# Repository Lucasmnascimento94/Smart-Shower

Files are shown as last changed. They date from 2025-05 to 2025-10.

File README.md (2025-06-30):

# Smart-Shower

This is an extended version of the project I made for my computer arquitecture class. 

# Goal
The Smart-Shower aims to provide a more efficient, personalized, and intelligent way to manage the shower experience. In many homes—mine included—it can take several minutes for water to reach a comfortable temperature due to the delay in hot water arriving through the pipes. Manually adjusting the valve each time is tedius and this system introduces a smart interface to control the shower valve (or other applicable valves) with a focus on user comfort, energy efficiency, and system safety.

# Features
-> Personalized Temperature Presets: Each user can save their preferred shower temperature settings for one-touch access.

-> Remote Start Functionality: Users can activate the shower remotely, allowing the water to reach the desired temperature before they step in—eliminating wait time.

-> Hot Water Monitoring: Tracks the decline of hot water temperature and alerts the user when they are about to run out—especially useful for homes that use hot water tanks.

-> Usage Tracking: Monitors water and energy usage per session. Data is logged and associated with individual users for long-term insights and potential conservation.

-> Cold Temperature Alert: Sends a warning if pipe temperatures drop too low, helping to prevent frozen or burst pipes—especially relevant for homes in colder northern climates (like mine).

# Planned Future Enhancements

-> Rich Media User Interface: Build an advanced touchscreen UI that supports media platforms such as Spotify and YouTube for a more immersive shower experience.

-> Metal Contamination Detection: Integrate a sensor to detect the presence of metals in the water—an issue that affects my home’s plumbing.

-> Smart Safety Alarms and Automation: Extend system logic to trigger alarms and automated valve actions based on detected anomalies in temperature or water quality.

The first version was made using an ATMEGA 168A, coded in assembly and all the assembled componnets were placed with loose wires in some protoboards. 

# Note
-> Because this application utilizes threads, I started to move away from the HAL functions. At first, when I started migrating from one thread to another multithreaded environment, I started adapting my working functions within certain threads. However, it was later on determined that the HAL function are not thread safe, and the programming was breaking randomly when trying to run some HAL functions. To solve this issue, I started to manipulate the register in a low level manner. Trying to avoid reinventing the wheel, I started reading the STM documentation and controlling the registers using the variable names in the RM and the macros that are provided in the STM header files. With this approach it was possible to create mutaxes and make sure that no race condition is preventing my code from running.

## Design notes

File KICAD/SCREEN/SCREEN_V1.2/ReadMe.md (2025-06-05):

## Update Overview - Power Distribution
  In this version, a critical flaw in the power distribution design has been corrected. Previously, the STM32F469IIT6 microcontroller was powered by an ASM1117-3.3 voltage regulator, stepping down from a 12V input. However, the resulting power dissipation caused the regulator to overheat, leading to unstable MCU behavior. The issue became more pronounced after introducing multi-threading in the firmware, which increased the system's current draw. At that point, the ASM1117 began to overheat severely, risking unpredictable system failures and potential board damage.

  This overheat was detected in a prior version where devices were powered by the same regulator. In an attempt to solve this issue and still use the same regulator (Because I have many in stock), I've added dedicated regulators for some devices and it worked at a certain degree. However, it was yet not possible to place the external flash memory without overheating the ASM that powers the STM32F469. Then this update aims to fix this flaw in order to be able to utilize all the intended devices and maintain the program reliability.  

## Update Overview - Touch Screen Controller
This version removes the XPT20 touchscreen controller from the design. In version 1.0 (not publicly released), issues with the touchscreen were caused by incorrect circuitry and the absence of a controller to compensate for it. The XPT20 was originally added as a workaround to assist with potential problems in reading ADC values directly—such as noise, hardware design flaws, or programming errors. However, in version 1.1, I successfully read the touchscreen using the STM32F469’s internal ADCs without needing the XPT20. As a result, this external controller has been removed in this version to simplify the design.

Version 1.1 also introduced multi-threading, with one dedicated thread continuously reading the X-axis ADC values. Based on these readings, the system calls the scan_ function, which samples multiple values to compute both X and Y coordinates. This function dynamically reconfigures the GPIOs to alternate between driving and reading different touchscreen lines. However, this dynamic GPIO switching proved problematic in a multithreaded environment. In this update, I'm testing a workaround by adding minimal extra circuitry and using an ADC multiplexer to eliminate the need for constant GPIO reconfiguration. The goal is to reduce the processing overhead and improve stability under concurrent execution.

## Update

| Removed Component |  New Component | Datasheet|
| ---:  | ---: | ---|
|AMS1117-3.3 |LM2576T-ADJ/NOPB  | https://www.ti.com/general/docs/suppproductinfo.tsp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|
| XPT20 | N/A | https://www.alldatasheet.com/html-pdf/1649104/ETC2/XPT2046/111/1/XPT2046.html |

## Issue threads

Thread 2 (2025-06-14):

Hardware | Ring Resistor

Lucasmnascimento94, 2025-06-14:
- Design a ring resistor using Nichrome wire
- Calibrate ring resistor to work as a rotation decoder

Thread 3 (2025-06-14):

Software | Valve - Position Decoder Function

Lucasmnascimento94, 2025-06-14:
- Create a function to decode ADC readings into motor's angular position
- Create a function to calibrate ring resistor in assembling process

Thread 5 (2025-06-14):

Software | Valve - Threads -> DS18B20 Function

Lucasmnascimento94, 2025-06-14:
**Create thread for Temperature Sensors**

- Read temperature from DS18B20 sensors
- Update global sensor structs

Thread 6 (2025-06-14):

Software | Valve - Threads -> UART Function

Lucasmnascimento94, 2025-06-14:
**Create a thread to handle UART**

- Configure UARTs in DMA mode to send data
- Configure UARTs in DMA mode to receive data
- Send data to memory
- Start UART transfer once data is completely transferred to memory
- Read data from memory and raise flag to indicate main thread that data is valid

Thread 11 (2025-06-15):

Create an ACK response with CRC/Checksum to check data sent

Lucasmnascimento94, 2025-06-15:
Initial results showed that the first data burst is being lost, so to avoid data loss and to make sure that commands are being received correctly, an ACK has to be implemented.

Lucasmnascimento94, 2025-07-12:
This function is now done. It reads the data received from DMA, and returns the number of bytes read, also in DMA mode.

Closed 2025-07-12.

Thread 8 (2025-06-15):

Configure UARTs in DMA mode to send data

Lucasmnascimento94, 2025-06-15:
It seems that HAL is not reliable to configure the DMA while using threads. Therefore, it is necessary to read about the DMA control register in the reference manual to control it in lower level.

###Correction###

- Writing directly in the register proved to be not efficient, and using HAL libraries is indeed a better approach.

-> DMA is now working, and mutexes were added to avoid race conditions.

Closed 2025-07-12.

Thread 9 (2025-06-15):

Configure UARTs in DMA mode to receive data

Lucasmnascimento94, 2025-06-15:

Lucasmnascimento94, 2025-07-12:
DMA_RECEIVE is now working. Mutexes are being used to avoid conflicts between DMA_RX and DMA_TX.

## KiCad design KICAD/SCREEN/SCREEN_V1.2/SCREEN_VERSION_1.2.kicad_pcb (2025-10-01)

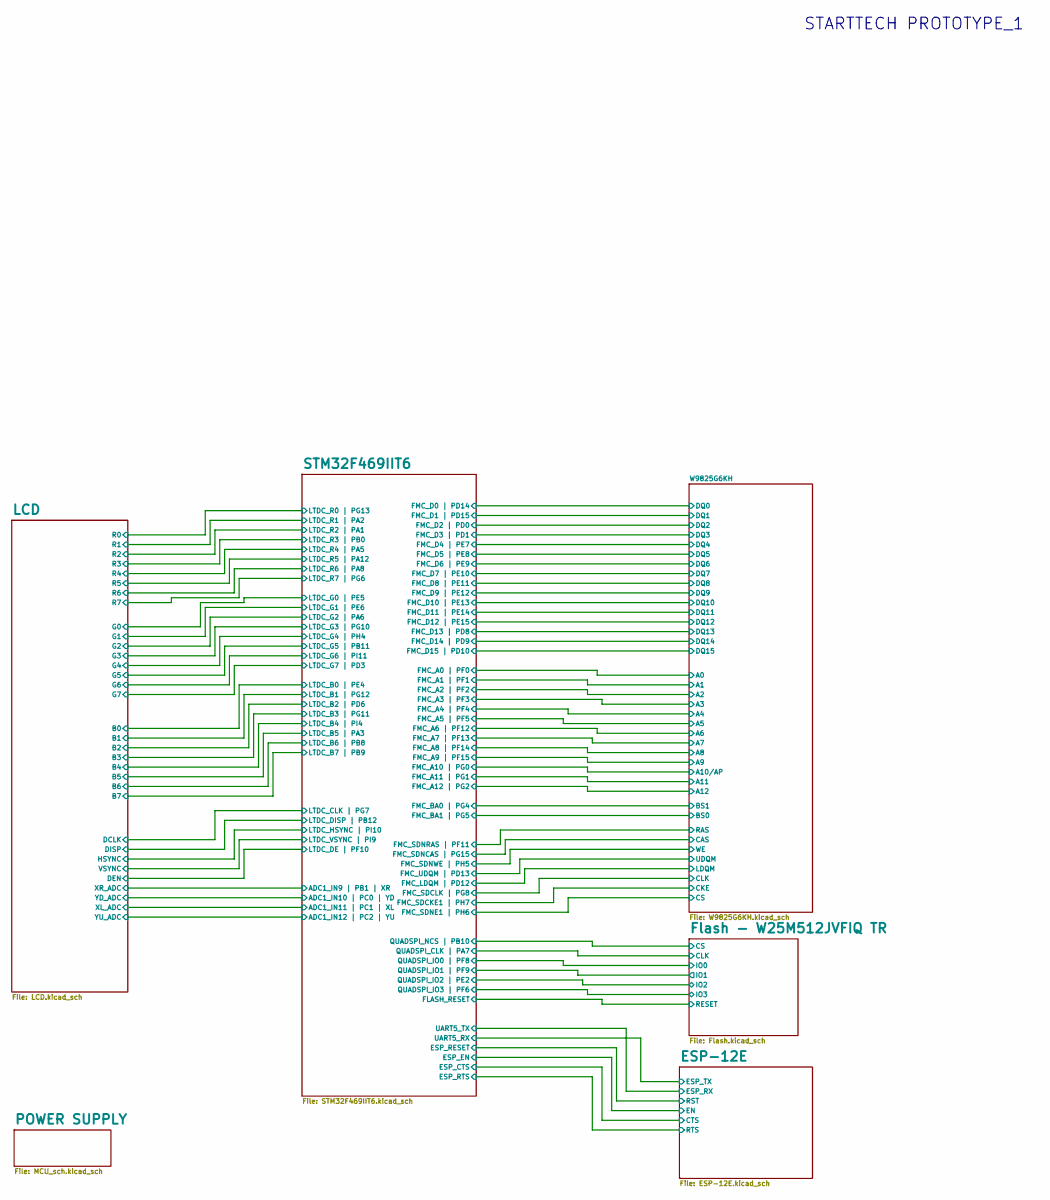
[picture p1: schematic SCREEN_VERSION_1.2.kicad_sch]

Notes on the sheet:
STARTTECH PROTOTYPE_1

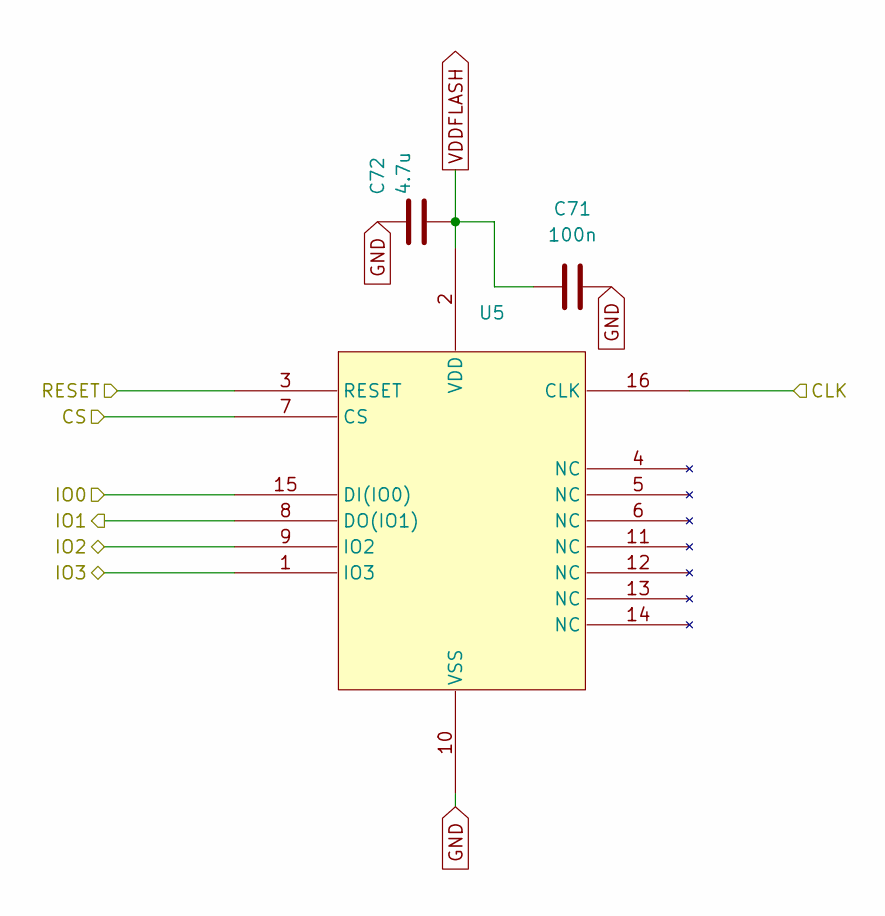
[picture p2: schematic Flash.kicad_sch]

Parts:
C71: 100n; C_0402_1005Metric
C72: 4.7u; C_0603_1608Metric
U5: W25M512JVFIQ

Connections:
/Flash - W25M512JVFIQ TR/CLK: U5.16 (CLK); also elsewhere on the board
/Flash - W25M512JVFIQ TR/CS: U5.7 (CS); also elsewhere on the board
/Flash - W25M512JVFIQ TR/IO0: U5.15 (DI(IO0)); also elsewhere on the board
/Flash - W25M512JVFIQ TR/IO1: U5.8 (DO(IO1)); also elsewhere on the board
/Flash - W25M512JVFIQ TR/IO2: U5.9 (IO2); also elsewhere on the board
/Flash - W25M512JVFIQ TR/IO3: U5.1 (IO3); also elsewhere on the board
/Flash - W25M512JVFIQ TR/RESET: U5.3 (RESET); also elsewhere on the board
GND: C71.2, C72.1, U5.10 (VSS); also elsewhere on the board
VDDFLASH: C71.1, C72.2, U5.2 (VDD); also elsewhere on the board

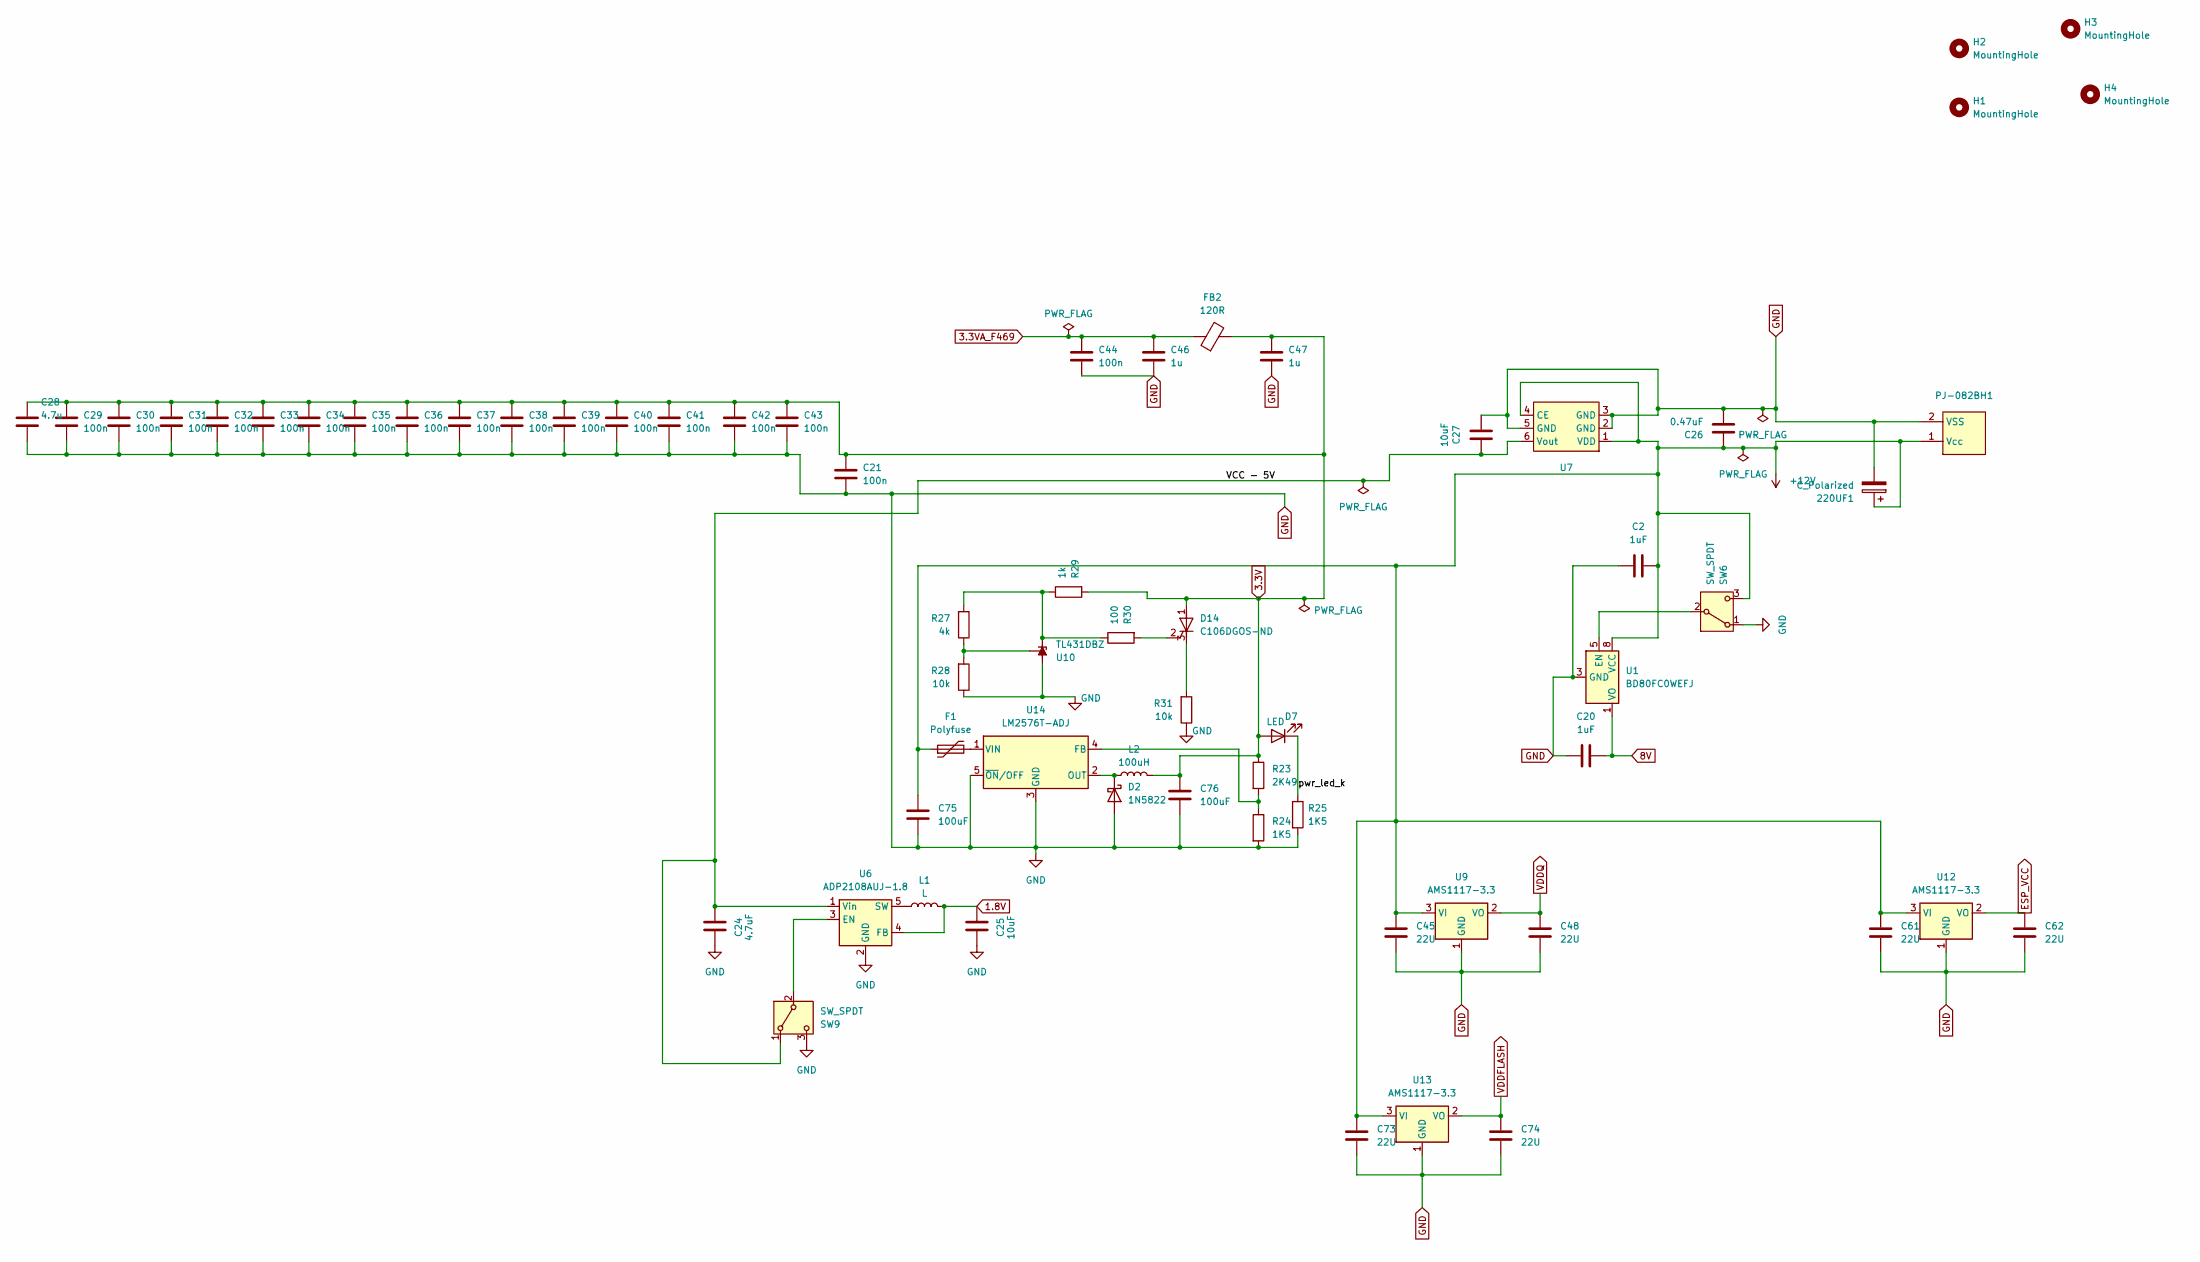
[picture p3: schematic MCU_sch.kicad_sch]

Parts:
220UF1: C_Polarized; C_Disc_D3.0mm_W1.6mm_P2.50mm
C2, C20: 1uF; C_0603_1608Metric
C21, C29, C30, C31, C32, C33, C34, C35, C36, C37, C38, C39, C40, C41, C42, C43, C44: 100n; C_0402_1005Metric
C24: 4.7uF; C_0603_1608Metric
C25, C27: 10uF; C_0805_2012Metric
C26: 0.47uF; C_0603_1608Metric
C28: 4.7u; C_0603_1608Metric
C45, C48, C61, C62, C73, C74: 22U; C_0805_2012Metric
C46, C47: 1u; C_0603_1608Metric
C75, C76: 100uF; C_1210_3225Metric_Pad1.33x2.70mm_HandSolder
D2: 1N5822; D_DO-201AD_P15.24mm_Horizontal
D7: LED; LED_0603_1608Metric
D14: C106DGOS-ND; SIP3_11.6x8.5mm
F1: Polyfuse; Fuse_1206_3216Metric
FB2: 120R; L_0603_1608Metric
H1, H2, H3, H4: MountingHole; MountingHole_3.2mm_M3
L1: L; L_0603_1608Metric_Pad1.05x0.95mm_HandSolder
L2: 100uH; SRN8040-101M
PJ-082BH1: BarrelJack_CUI_PJ-063AH_Horizontal
R23: 2K49; R_0402_1005Metric
R24, R25: 1K5; R_0402_1005Metric
R27: 4k; R_0402_1005Metric
R28, R31: 10k; R_0402_1005Metric
R29: 1k; R_0402_1005Metric
R30: 100; R_0402_1005Metric
SW6, SW9: SW_SPDT; SW_Slide_SPDT_Straight_CK_OS102011MS2Q
U1: BD80FC0WEFJ; HTSOP-8-1EP_3.9x4.9mm_P1.27mm_EP2.4x3.2mm
U6: ADP2108AUJ-1.8; TSOT-23-5
U7: R1501S050B-E2-FE
U9, U12, U13: AMS1117-3.3; SOT-223-3_TabPin2
U10: TL431DBZ; SOT-23
U14: LM2576T-ADJ; TO-220-5_Vertical

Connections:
1.8V: C25.1, L1.2, U6.4 (FB); also elsewhere on the board
3.3V: C21.1, C28.1, C29.1, C30.1, C31.1, C32.1, C33.1, C34.1, C35.1, C36.1, C37.1, C38.1, C39.1, C40.1, C41.1, C42.1, C43.1, C47.1, C76.1, D7.2 (A), D14.1 (A), FB2.2, L2.2, R23.1, R29.2; also elsewhere on the board
3.3VA_F469: C44.1, C46.1, FB2.1; also elsewhere on the board
8V: C20.1, U1.1 (VO); also elsewhere on the board
+12V: 220UF1.1, C2.1, C26.1, C45.1, C61.1, C73.1, C75.1, F1.1, PJ-082BH1.1 (Vcc), SW6.3 (C), U1.8 (VCC), U7.1 (VDD), U7.4 (CE), U9.3 (VI), U12.3 (VI), U13.3 (VI)
/POWER SUPPLY/VCC - 5V: C24.1, C27.2, SW9.1 (A), U6.1 (Vin), U7.6 (Vout)
/POWER SUPPLY/pwr_led_k: D7.1 (K), R25.1
ESP_VCC: C62.1, U12.2 (VO); also elsewhere on the board
GND: 220UF1.2, C2.2, C20.2, C21.2, C24.2, C25.2, C26.2, C27.1, C28.2, C29.2, C30.2, C31.2, C32.2, C33.2, C34.2, C35.2, C36.2, C37.2, C38.2, C39.2, C40.2, C41.2, C42.2, C43.2, C44.2, C45.2, C46.2, C47.2, C48.2, C61.2, C62.2, C73.2, C74.2, C75.2, C76.2, D2.2 (A), PJ-082BH1.2 (VSS), R24.2, R25.2, R28.1, R31.1, SW6.1 (A), SW9.3 (C), U1.3 (GND), U1.9 (GND), U6.2 (GND), U7.2 (GND), U7.3 (GND), U7.5 (GND), U9.1 (GND), U10.3 (A), U12.1 (GND), U13.1 (GND), U14.3 (GND), U14.5 (~ON/OFF); also elsewhere on the board
unnamed: D2.1 (K), L2.1, U14.2 (OUT)
unnamed: D14.2 (G), R30.2
unnamed: D14.3 (K), R31.2
unnamed: SW6.2 (B), U1.5 (EN)
unnamed: SW9.2 (B), U6.3 (EN)
unnamed: L1.1, U6.5 (SW)
unnamed: R27.2, R29.1, R30.1, U10.1 (K)
unnamed: R27.1, R28.2, U10.2 (REF)
unnamed: R23.2, R24.1, U14.4 (FB)
unnamed: F1.2, U14.1 (VIN)
VDDFLASH: C74.1, U13.2 (VO); also elsewhere on the board
VDDQ: C48.1, U9.2 (VO); also elsewhere on the board

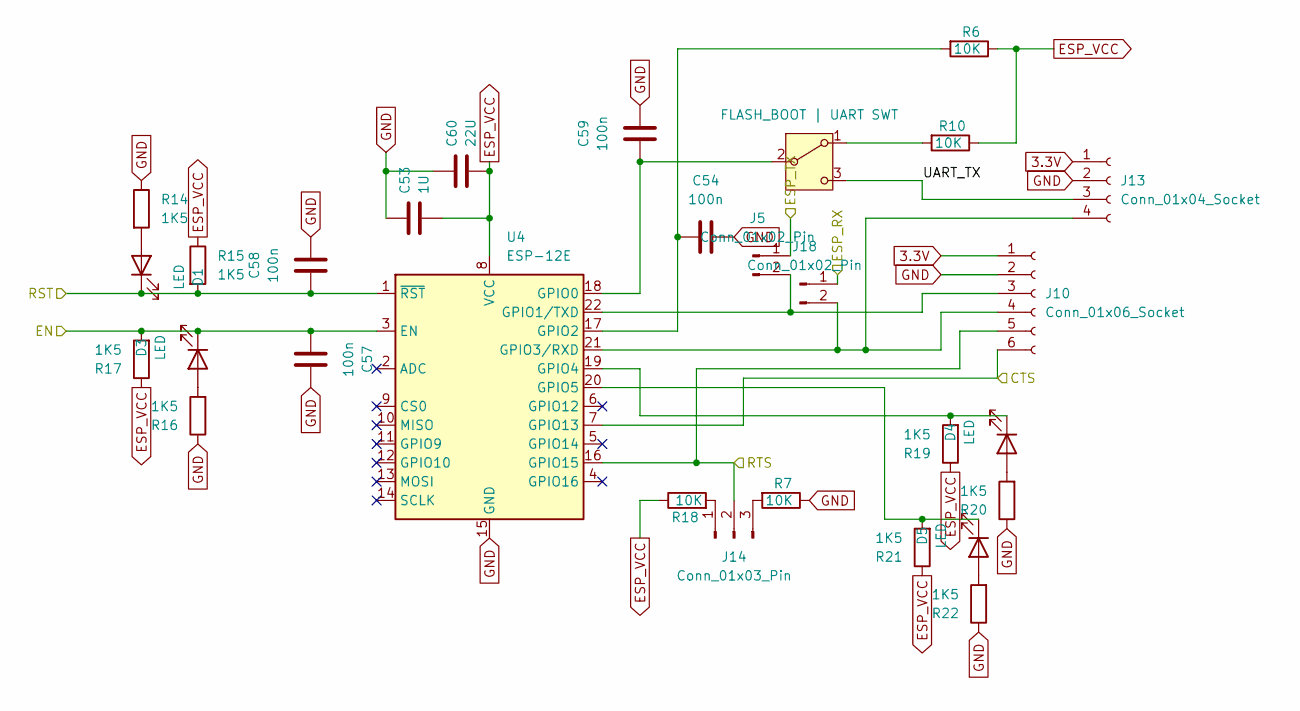
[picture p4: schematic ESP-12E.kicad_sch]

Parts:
C53: 1U; C_0805_2012Metric
C54, C57, C58, C59: 100n; C_0402_1005Metric
C60: 22U; C_0805_2012Metric
D1, D3, D4, D5: LED; LED_0603_1608Metric
J5, J18: Conn_01x02_Pin; PinSocket_1x02_P2.54mm_Vertical
J10: Conn_01x06_Socket; PinSocket_1x06_P2.54mm_Vertical
J13: Conn_01x04_Socket; PinSocket_1x04_P2.54mm_Vertical
J14: Conn_01x03_Pin; PinSocket_1x03_P2.54mm_Vertical
R6, R7, R10, R18: 10K; R_0402_1005Metric
R14, R15, R16, R17, R19, R20, R21, R22: 1K5; R_0402_1005Metric
SW5: FLASH_BOOT | UART SWT; SW_Slide_SPDT_Straight_CK_OS102011MS2Q
U4: ESP-12E

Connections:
3.3V: J10.1, J13.1; also elsewhere on the board
/ESP-12E/CTS: J10.6, U4.7 (GPIO13); also elsewhere on the board
/ESP-12E/EN: C57.1, D3.1 (K), R17.2, U4.3 (EN); also elsewhere on the board
/ESP-12E/ESP_RX: J18.1; also elsewhere on the board
/ESP-12E/ESP_TX: J5.1; also elsewhere on the board
/ESP-12E/RST: C58.1, D1.1 (K), R15.2, U4.1 (~RST); also elsewhere on the board
/ESP-12E/RTS: J10.5, J14.2, U4.16 (GPIO15); also elsewhere on the board
/ESP-12E/UART_TX: J13.3, SW5.3 (C)
ESP_VCC: C53.2, C60.2, R6.1, R10.1, R15.1, R17.1, R18.1, R19.1, R21.1, U4.8 (VCC); also elsewhere on the board
GND: C53.1, C54.2, C57.2, C58.2, C59.2, C60.1, J10.2, J13.2, R7.1, R14.1, R16.1, R20.1, R22.1, U4.15 (GND); also elsewhere on the board
unnamed: D1.2 (A), R14.2
unnamed: D3.2 (A), R16.2
unnamed: D4.2 (A), R20.2
unnamed: D4.1 (K), R19.2, U4.19 (GPIO4)
unnamed: D5.2 (A), R22.2
unnamed: D5.1 (K), R21.2, U4.20 (GPIO5)
unnamed: J5.2, J10.3, U4.22 (GPIO1/TXD)
unnamed: J10.4, J13.4, J18.2, U4.21 (GPIO3/RXD)
unnamed: J14.1, R18.2
unnamed: J14.3, R7.2
unnamed: R10.2, SW5.1 (A)
unnamed: C59.1, SW5.2 (B), U4.18 (GPIO0)
unnamed: C54.1, R6.2, U4.17 (GPIO2)

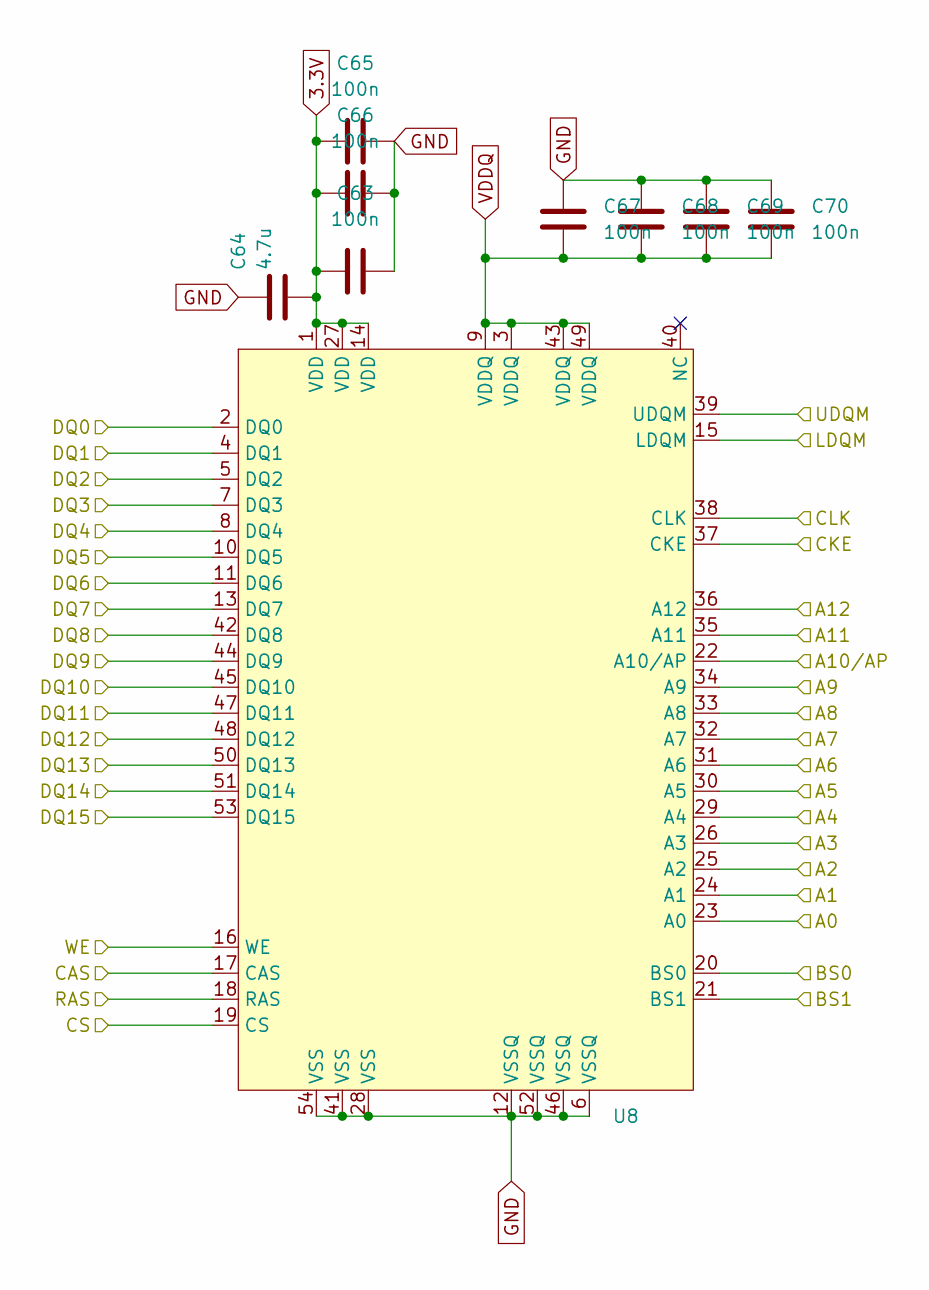
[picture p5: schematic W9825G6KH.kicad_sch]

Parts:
C63, C65, C66, C67, C68, C69, C70: 100n; C_0402_1005Metric
C64: 4.7u; C_0603_1608Metric
U8: W9825G6KH

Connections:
3.3V: C63.1, C64.2, C65.1, C66.1, U8.1 (VDD), U8.14 (VDD), U8.27 (VDD); also elsewhere on the board
/STM32F469IIT6/FMC_A0 | PF0: U8.23 (A0); also elsewhere on the board
/STM32F469IIT6/FMC_A1 | PF1: U8.24 (A1); also elsewhere on the board
/STM32F469IIT6/FMC_A2 | PF2: U8.25 (A2); also elsewhere on the board
/STM32F469IIT6/FMC_A3 | PF3: U8.26 (A3); also elsewhere on the board
/STM32F469IIT6/FMC_A4 | PF4: U8.29 (A4); also elsewhere on the board
/STM32F469IIT6/FMC_A5 | PF5: U8.30 (A5); also elsewhere on the board
/STM32F469IIT6/FMC_A6 | PF12: U8.31 (A6); also elsewhere on the board
/STM32F469IIT6/FMC_A7 | PF13: U8.32 (A7); also elsewhere on the board
/STM32F469IIT6/FMC_A8 | PF14: U8.33 (A8); also elsewhere on the board
/STM32F469IIT6/FMC_A9 | PF15: U8.34 (A9); also elsewhere on the board
/STM32F469IIT6/FMC_A10 | PG0: U8.22 (A10/AP); also elsewhere on the board
/STM32F469IIT6/FMC_A11 | PG1: U8.35 (A11); also elsewhere on the board
/STM32F469IIT6/FMC_A12 | PG2: U8.36 (A12); also elsewhere on the board
/STM32F469IIT6/FMC_BA0 | PG4: U8.21 (BS1); also elsewhere on the board
/STM32F469IIT6/FMC_BA1 | PG5: U8.20 (BS0); also elsewhere on the board
/STM32F469IIT6/FMC_D0 | PD14: U8.2 (DQ0); also elsewhere on the board
/STM32F469IIT6/FMC_D1 | PD15: U8.4 (DQ1); also elsewhere on the board
/STM32F469IIT6/FMC_D2 | PD0: U8.5 (DQ2); also elsewhere on the board
/STM32F469IIT6/FMC_D3 | PD1: U8.7 (DQ3); also elsewhere on the board
/STM32F469IIT6/FMC_D4 | PE7: U8.8 (DQ4); also elsewhere on the board
/STM32F469IIT6/FMC_D5 | PE8: U8.10 (DQ5); also elsewhere on the board
/STM32F469IIT6/FMC_D6 | PE9: U8.11 (DQ6); also elsewhere on the board
/STM32F469IIT6/FMC_D7 | PE10: U8.13 (DQ7); also elsewhere on the board
/STM32F469IIT6/FMC_D8 | PE11: U8.42 (DQ8); also elsewhere on the board
/STM32F469IIT6/FMC_D9 | PE12: U8.44 (DQ9); also elsewhere on the board
/STM32F469IIT6/FMC_D10 | PE13: U8.45 (DQ10); also elsewhere on the board
/STM32F469IIT6/FMC_D11 | PE14: U8.47 (DQ11); also elsewhere on the board
/STM32F469IIT6/FMC_D12 | PE15: U8.48 (DQ12); also elsewhere on the board
/STM32F469IIT6/FMC_D13 | PD8: U8.50 (DQ13); also elsewhere on the board
/STM32F469IIT6/FMC_D14 | PD9: U8.51 (DQ14); also elsewhere on the board
/STM32F469IIT6/FMC_D15 | PD10: U8.53 (DQ15); also elsewhere on the board
/STM32F469IIT6/FMC_LDQM | PD12: U8.15 (LDQM); also elsewhere on the board
/STM32F469IIT6/FMC_SDCKE1 | PH7: U8.37 (CKE); also elsewhere on the board
/STM32F469IIT6/FMC_SDCLK | PG8: U8.38 (CLK); also elsewhere on the board
/STM32F469IIT6/FMC_SDNCAS | PG15: U8.17 (CAS); also elsewhere on the board
/STM32F469IIT6/FMC_SDNE1 | PH6: U8.19 (CS); also elsewhere on the board
/STM32F469IIT6/FMC_SDNRAS | PF11: U8.18 (RAS); also elsewhere on the board
/STM32F469IIT6/FMC_SDNWE | PH5: U8.16 (WE); also elsewhere on the board
/STM32F469IIT6/FMC_UDQM | PD13: U8.39 (UDQM); also elsewhere on the board
GND: C63.2, C64.1, C65.2, C66.2, C67.2, C68.2, C69.2, C70.2, U8.6 (VSSQ), U8.12 (VSSQ), U8.28 (VSS), U8.41 (VSS), U8.46 (VSSQ), U8.52 (VSSQ), U8.54 (VSS); also elsewhere on the board
VDDQ: C67.1, C68.1, C69.1, C70.1, U8.3 (VDDQ), U8.9 (VDDQ), U8.43 (VDDQ), U8.49 (VDDQ); also elsewhere on the board

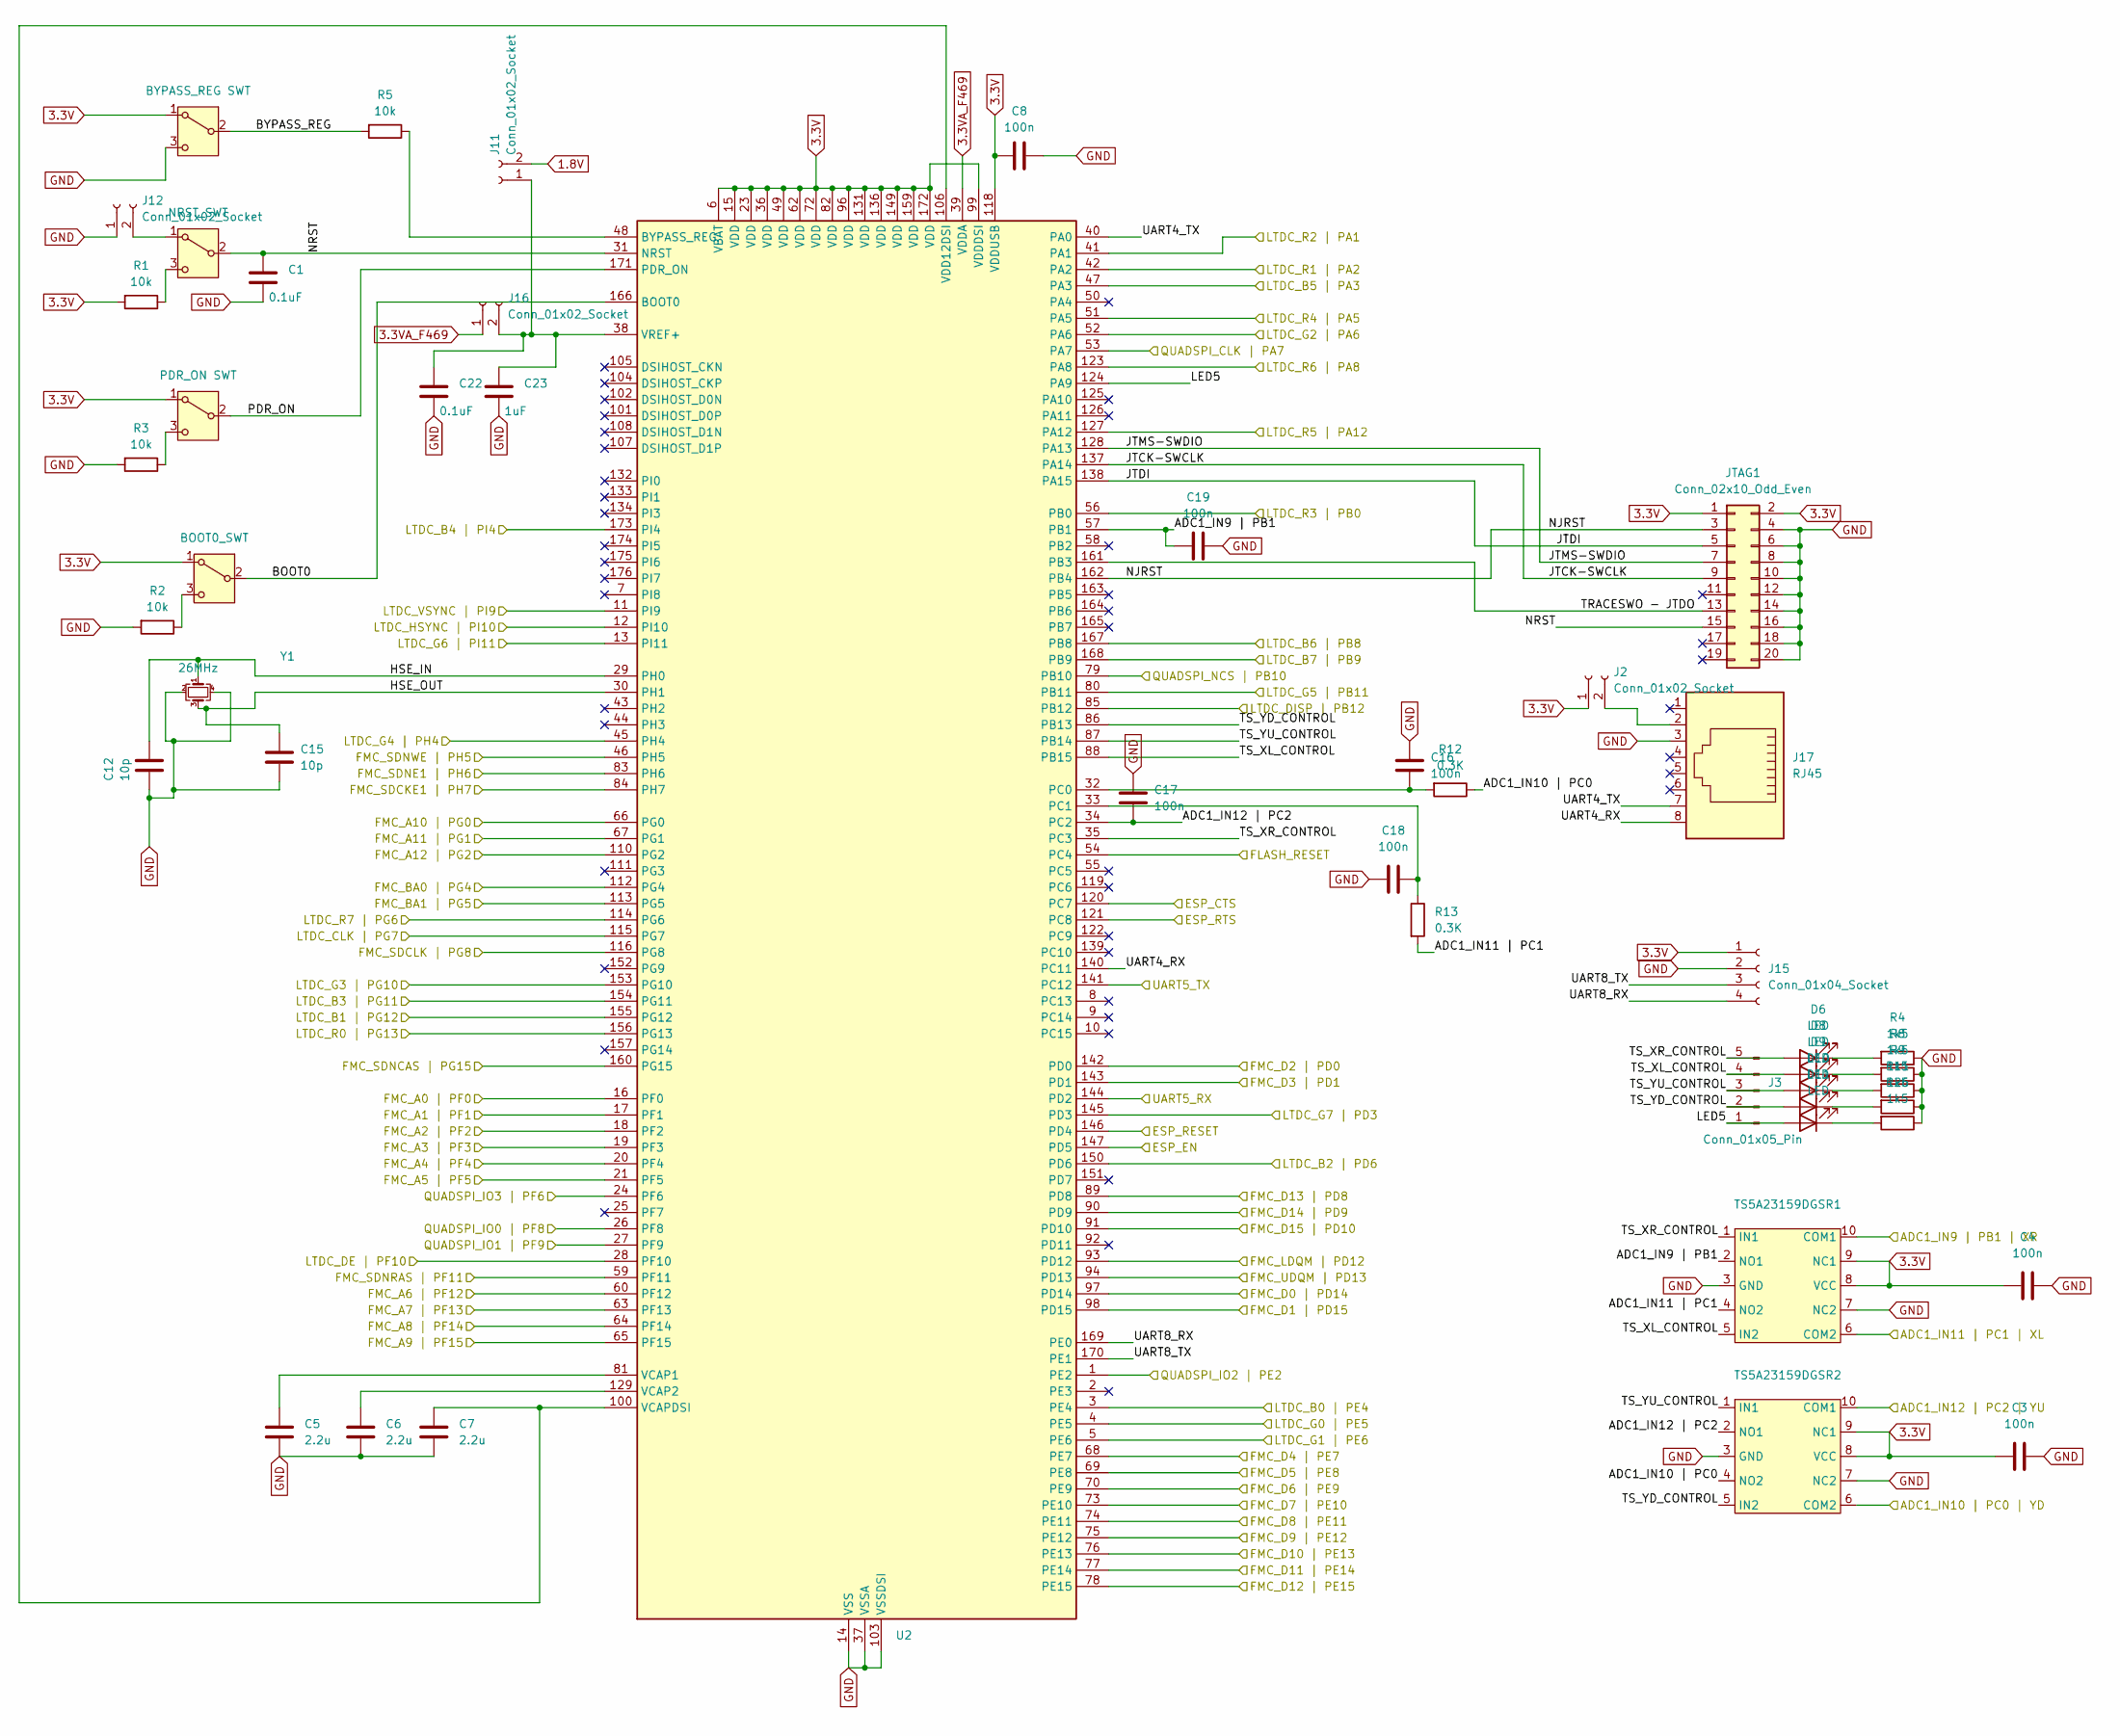
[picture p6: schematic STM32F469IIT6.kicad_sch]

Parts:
C1, C22: 0.1uF; C_0402_1005Metric
C3, C4, C8, C16, C17, C18, C19: 100n; C_0402_1005Metric
C5, C6, C7: 2.2u; C_0402_1005Metric
C12, C15: 10p; C_0402_1005Metric
C23: 1uF; C_0402_1005Metric
D6, D8, D9, D10, D11: LED; LED_0603_1608Metric
J2, J11, J12, J16: Conn_01x02_Socket; PinSocket_1x02_P2.54mm_Vertical
J3: Conn_01x05_Pin; PinSocket_1x05_P2.54mm_Vertical
J15: Conn_01x04_Socket; PinSocket_1x04_P2.54mm_Vertical
J17: RJ45; RJ45_Pulse_JXD6-0001NL_Horizontal
JTAG1: Conn_02x10_Odd_Even; IDC-Header_2x10_P2.54mm_Vertical
R1, R2, R3, R5: 10k; R_0402_1005Metric
R4, R8, R9, R11, R26: 1k5; R_0402_1005Metric
R12, R13: 0.3K; R_0402_1005Metric
SW1: BOOT0_SWT; SW_Slide_SPDT_Straight_CK_OS102011MS2Q
SW2: NRST_SWT; SW_Slide_SPDT_Straight_CK_OS102011MS2Q
SW3: PDR_ON SWT; SW_Slide_SPDT_Straight_CK_OS102011MS2Q
SW4: BYPASS_REG SWT; SW_Slide_SPDT_Straight_CK_OS102011MS2Q
TS5A23159DGSR1, TS5A23159DGSR2: TS5A23159DGSR
U2: STM32F469IITx; LQFP-176_24x24mm_P0.5mm
Y1: 26MHz; Crystal_SMD_3225-4Pin_3.2x2.5mm_HandSoldering

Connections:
1.8V: J11.2; also elsewhere on the board
3.3V: C3.1, C4.1, C8.1, J2.1, J15.1, JTAG1.1, JTAG1.2, R1.2, SW1.1 (A), SW3.1 (A), SW4.1 (A), TS5A23159DGSR1.8 (VCC), TS5A23159DGSR1.9 (NC1), TS5A23159DGSR2.8 (VCC), TS5A23159DGSR2.9 (NC1), U2.6 (VBAT), U2.15 (VDD), U2.23 (VDD), U2.36 (VDD), U2.49 (VDD), U2.62 (VDD), U2.72 (VDD), U2.82 (VDD), U2.96 (VDD), U2.99 (VDDDSI), U2.118 (VDDUSB), U2.131 (VDD), U2.136 (VDD), U2.149 (VDD), U2.159 (VDD), U2.172 (VDD); also elsewhere on the board
3.3VA_F469: J16.1, U2.39 (VDDA); also elsewhere on the board
/ESP-12E/CTS: U2.120 (PC7); also elsewhere on the board
/ESP-12E/EN: U2.147 (PD5); also elsewhere on the board
/ESP-12E/ESP_RX: U2.141 (PC12); also elsewhere on the board
/ESP-12E/ESP_TX: U2.144 (PD2); also elsewhere on the board
/ESP-12E/RST: U2.146 (PD4); also elsewhere on the board
/ESP-12E/RTS: U2.121 (PC8); also elsewhere on the board
/Flash - W25M512JVFIQ TR/CLK: U2.53 (PA7); also elsewhere on the board
/Flash - W25M512JVFIQ TR/CS: U2.79 (PB10); also elsewhere on the board
/Flash - W25M512JVFIQ TR/IO0: U2.26 (PF8); also elsewhere on the board
/Flash - W25M512JVFIQ TR/IO1: U2.27 (PF9); also elsewhere on the board
/Flash - W25M512JVFIQ TR/IO2: U2.1 (PE2); also elsewhere on the board
/Flash - W25M512JVFIQ TR/IO3: U2.24 (PF6); also elsewhere on the board
/Flash - W25M512JVFIQ TR/RESET: U2.54 (PC4); also elsewhere on the board
/LCD/B0: U2.3 (PE4); also elsewhere on the board
/LCD/B1: U2.155 (PG12); also elsewhere on the board
/LCD/B2: U2.150 (PD6); also elsewhere on the board
/LCD/B3: U2.154 (PG11); also elsewhere on the board
/LCD/B4: U2.173 (PI4); also elsewhere on the board
/LCD/B5: U2.47 (PA3); also elsewhere on the board
/LCD/B6: U2.167 (PB8); also elsewhere on the board
/LCD/B7: U2.168 (PB9); also elsewhere on the board
/LCD/DCLK: U2.115 (PG7); also elsewhere on the board
/LCD/DEN: U2.28 (PF10); also elsewhere on the board
/LCD/DISP: U2.85 (PB12); also elsewhere on the board
/LCD/G0: U2.4 (PE5); also elsewhere on the board
/LCD/G1: U2.5 (PE6); also elsewhere on the board
/LCD/G2: U2.52 (PA6); also elsewhere on the board
/LCD/G3: U2.153 (PG10); also elsewhere on the board
/LCD/G4: U2.45 (PH4); also elsewhere on the board
/LCD/G5: U2.80 (PB11); also elsewhere on the board
/LCD/G6: U2.13 (PI11); also elsewhere on the board
/LCD/G7: U2.145 (PD3); also elsewhere on the board
/LCD/HSYNC: U2.12 (PI10); also elsewhere on the board
/LCD/R0: U2.156 (PG13); also elsewhere on the board
/LCD/R1: U2.42 (PA2); also elsewhere on the board
/LCD/R2: U2.41 (PA1); also elsewhere on the board
/LCD/R3: U2.56 (PB0); also elsewhere on the board
/LCD/R4: U2.51 (PA5); also elsewhere on the board
/LCD/R5: U2.127 (PA12); also elsewhere on the board
/LCD/R6: U2.123 (PA8); also elsewhere on the board
/LCD/R7: U2.114 (PG6); also elsewhere on the board
/LCD/VSYNC: U2.11 (PI9); also elsewhere on the board
/LCD/XL_ADC: TS5A23159DGSR1.6 (COM2); also elsewhere on the board
/LCD/XR_ADC: TS5A23159DGSR1.10 (COM1); also elsewhere on the board
/LCD/YD_ADC: TS5A23159DGSR2.6 (COM2); also elsewhere on the board
/LCD/YU_ADC: TS5A23159DGSR2.10 (COM1); also elsewhere on the board
/STM32F469IIT6/ADC1_IN9 | PB1: C19.1, TS5A23159DGSR1.2 (NO1), U2.57 (PB1)
/STM32F469IIT6/ADC1_IN10 | PC0: R12.1, TS5A23159DGSR2.4 (NO2)
/STM32F469IIT6/ADC1_IN11 | PC1: R13.2, TS5A23159DGSR1.4 (NO2)
/STM32F469IIT6/ADC1_IN12 | PC2: C17.2, TS5A23159DGSR2.2 (NO1), U2.34 (PC2)
/STM32F469IIT6/BOOT0: SW1.2 (B), U2.166 (BOOT0); also elsewhere on the board
/STM32F469IIT6/BYPASS_REG: R5.2, SW4.2 (B); also elsewhere on the board
/STM32F469IIT6/FMC_A0 | PF0: U2.16 (PF0); also elsewhere on the board
/STM32F469IIT6/FMC_A1 | PF1: U2.17 (PF1); also elsewhere on the board
/STM32F469IIT6/FMC_A2 | PF2: U2.18 (PF2); also elsewhere on the board
/STM32F469IIT6/FMC_A3 | PF3: U2.19 (PF3); also elsewhere on the board
/STM32F469IIT6/FMC_A4 | PF4: U2.20 (PF4); also elsewhere on the board
/STM32F469IIT6/FMC_A5 | PF5: U2.21 (PF5); also elsewhere on the board
/STM32F469IIT6/FMC_A6 | PF12: U2.60 (PF12); also elsewhere on the board
/STM32F469IIT6/FMC_A7 | PF13: U2.63 (PF13); also elsewhere on the board
/STM32F469IIT6/FMC_A8 | PF14: U2.64 (PF14); also elsewhere on the board
/STM32F469IIT6/FMC_A9 | PF15: U2.65 (PF15); also elsewhere on the board
/STM32F469IIT6/FMC_A10 | PG0: U2.66 (PG0); also elsewhere on the board
/STM32F469IIT6/FMC_A11 | PG1: U2.67 (PG1); also elsewhere on the board
/STM32F469IIT6/FMC_A12 | PG2: U2.110 (PG2); also elsewhere on the board
/STM32F469IIT6/FMC_BA0 | PG4: U2.112 (PG4); also elsewhere on the board
/STM32F469IIT6/FMC_BA1 | PG5: U2.113 (PG5); also elsewhere on the board
/STM32F469IIT6/FMC_D0 | PD14: U2.97 (PD14); also elsewhere on the board
/STM32F469IIT6/FMC_D1 | PD15: U2.98 (PD15); also elsewhere on the board
/STM32F469IIT6/FMC_D2 | PD0: U2.142 (PD0); also elsewhere on the board
/STM32F469IIT6/FMC_D3 | PD1: U2.143 (PD1); also elsewhere on the board
/STM32F469IIT6/FMC_D4 | PE7: U2.68 (PE7); also elsewhere on the board
/STM32F469IIT6/FMC_D5 | PE8: U2.69 (PE8); also elsewhere on the board
/STM32F469IIT6/FMC_D6 | PE9: U2.70 (PE9); also elsewhere on the board
/STM32F469IIT6/FMC_D7 | PE10: U2.73 (PE10); also elsewhere on the board
/STM32F469IIT6/FMC_D8 | PE11: U2.74 (PE11); also elsewhere on the board
/STM32F469IIT6/FMC_D9 | PE12: U2.75 (PE12); also elsewhere on the board
/STM32F469IIT6/FMC_D10 | PE13: U2.76 (PE13); also elsewhere on the board
/STM32F469IIT6/FMC_D11 | PE14: U2.77 (PE14); also elsewhere on the board
/STM32F469IIT6/FMC_D12 | PE15: U2.78 (PE15); also elsewhere on the board
/STM32F469IIT6/FMC_D13 | PD8: U2.89 (PD8); also elsewhere on the board
/STM32F469IIT6/FMC_D14 | PD9: U2.90 (PD9); also elsewhere on the board
/STM32F469IIT6/FMC_D15 | PD10: U2.91 (PD10); also elsewhere on the board
/STM32F469IIT6/FMC_LDQM | PD12: U2.93 (PD12); also elsewhere on the board
/STM32F469IIT6/FMC_SDCKE1 | PH7: U2.84 (PH7); also elsewhere on the board
/STM32F469IIT6/FMC_SDCLK | PG8: U2.116 (PG8); also elsewhere on the board
/STM32F469IIT6/FMC_SDNCAS | PG15: U2.160 (PG15); also elsewhere on the board
/STM32F469IIT6/FMC_SDNE1 | PH6: U2.83 (PH6); also elsewhere on the board
/STM32F469IIT6/FMC_SDNRAS | PF11: U2.59 (PF11); also elsewhere on the board
/STM32F469IIT6/FMC_SDNWE | PH5: U2.46 (PH5); also elsewhere on the board
/STM32F469IIT6/FMC_UDQM | PD13: U2.94 (PD13); also elsewhere on the board
/STM32F469IIT6/HSE_IN: C12.1, U2.29 (PH0), Y1.1
/STM32F469IIT6/HSE_OUT: C15.1, U2.30 (PH1), Y1.3
/STM32F469IIT6/JTCK-SWCLK: JTAG1.9, U2.137 (PA14)
/STM32F469IIT6/JTDI: JTAG1.5, U2.138 (PA15)
/STM32F469IIT6/JTMS-SWDIO: JTAG1.7, U2.128 (PA13)
/STM32F469IIT6/LED5: D11.2 (A), J3.1, U2.124 (PA9)
/STM32F469IIT6/NJRST: JTAG1.3, U2.162 (PB4)
/STM32F469IIT6/NRST: C1.2, JTAG1.15, SW2.2 (B), U2.31 (NRST); also elsewhere on the board
/STM32F469IIT6/PDR_ON: SW3.2 (B), U2.171 (PDR_ON); also elsewhere on the board
/STM32F469IIT6/TRACESWO - JTDO: JTAG1.13, U2.161 (PB3)
/STM32F469IIT6/TS_XL_CONTROL: D8.2 (A), J3.4, TS5A23159DGSR1.5 (IN2), U2.88 (PB15)
/STM32F469IIT6/TS_XR_CONTROL: D6.2 (A), J3.5, TS5A23159DGSR1.1 (IN1), U2.35 (PC3)
/STM32F469IIT6/TS_YD_CONTROL: D10.2 (A), J3.2, TS5A23159DGSR2.5 (IN2), U2.86 (PB13)
/STM32F469IIT6/TS_YU_CONTROL: D9.2 (A), J3.3, TS5A23159DGSR2.1 (IN1), U2.87 (PB14)
/STM32F469IIT6/UART4_RX: J17.8, U2.140 (PC11)
/STM32F469IIT6/UART4_TX: J17.7, U2.40 (PA0)
/STM32F469IIT6/UART8_RX: J15.4, U2.169 (PE0)
/STM32F469IIT6/UART8_TX: J15.3, U2.170 (PE1)
GND: C1.1, C3.2, C4.2, C5.2, C6.2, C7.2, C8.2, C12.2, C15.2, C16.1, C17.1, C18.1, C19.2, C22.1, C23.1, J12.1, J15.2, J17.3, JTAG1.4, JTAG1.6, JTAG1.8, JTAG1.10, JTAG1.12, JTAG1.14, JTAG1.16, JTAG1.18, JTAG1.20, R2.2, R3.2, R4.1, R8.1, R9.1, R11.1, R26.1, SW4.3 (C), TS5A23159DGSR1.3 (GND), TS5A23159DGSR1.7 (NC2), TS5A23159DGSR2.3 (GND), TS5A23159DGSR2.7 (NC2), U2.14 (VSS), U2.22 (VSS), U2.37 (VSSA), U2.61 (VSS), U2.71 (VSS), U2.95 (VSS), U2.103 (VSSDSI), U2.109 (VSSDSI), U2.117 (VSS), U2.130 (VSS), U2.135 (VSS), U2.148 (VSS), U2.158 (VSS), Y1.2, Y1.4; also elsewhere on the board
unnamed: D6.1 (K), R4.2
unnamed: D8.1 (K), R8.2
unnamed: D9.1 (K), R9.2
unnamed: D10.1 (K), R11.2
unnamed: D11.1 (K), R26.2
unnamed: J2.2, J17.2
unnamed: C22.2, C23.2, J11.1, J16.2, U2.38 (VREF+)
unnamed 137: J12.2, SW2.1 (A); also elsewhere on the board
unnamed 140: R2.1, SW1.3 (C); also elsewhere on the board
unnamed 141: R1.1, SW2.3 (C); also elsewhere on the board
unnamed 142: R3.1, SW3.3 (C); also elsewhere on the board
unnamed: R5.1, U2.48 (BYPASS_REG)
unnamed: C16.2, R12.2, U2.32 (PC0)
unnamed: C18.2, R13.1, U2.33 (PC1)
unnamed: C5.1, U2.81 (VCAP1)
unnamed: C6.1, U2.129 (VCAP2)
unnamed: C7.1, U2.100 (VCAPDSI), U2.106 (VDD12DSI)

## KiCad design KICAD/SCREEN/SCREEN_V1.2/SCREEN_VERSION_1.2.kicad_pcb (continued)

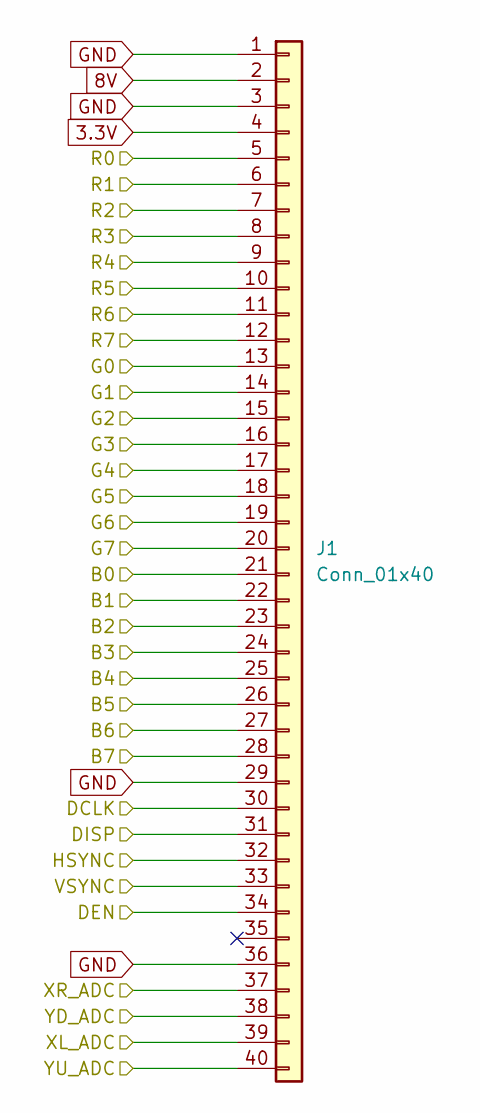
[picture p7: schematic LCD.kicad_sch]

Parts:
J1: Conn_01x40; Hirose_FH12-40S-0.5SH_1x40-1MP_P0.50mm_Horizontal

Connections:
3.3V: J1.4; also elsewhere on the board
8V: J1.2; also elsewhere on the board
/LCD/B0: J1.21; also elsewhere on the board
/LCD/B1: J1.22; also elsewhere on the board
/LCD/B2: J1.23; also elsewhere on the board
/LCD/B3: J1.24; also elsewhere on the board
/LCD/B4: J1.25; also elsewhere on the board
/LCD/B5: J1.26; also elsewhere on the board
/LCD/B6: J1.27; also elsewhere on the board
/LCD/B7: J1.28; also elsewhere on the board
/LCD/DCLK: J1.30; also elsewhere on the board
/LCD/DEN: J1.34; also elsewhere on the board
/LCD/DISP: J1.31; also elsewhere on the board
/LCD/G0: J1.13; also elsewhere on the board
/LCD/G1: J1.14; also elsewhere on the board
/LCD/G2: J1.15; also elsewhere on the board
/LCD/G3: J1.16; also elsewhere on the board
/LCD/G4: J1.17; also elsewhere on the board
/LCD/G5: J1.18; also elsewhere on the board
/LCD/G6: J1.19; also elsewhere on the board
/LCD/G7: J1.20; also elsewhere on the board
/LCD/HSYNC: J1.32; also elsewhere on the board
/LCD/R0: J1.5; also elsewhere on the board
/LCD/R1: J1.6; also elsewhere on the board
/LCD/R2: J1.7; also elsewhere on the board
/LCD/R3: J1.8; also elsewhere on the board
/LCD/R4: J1.9; also elsewhere on the board
/LCD/R5: J1.10; also elsewhere on the board
/LCD/R6: J1.11; also elsewhere on the board
/LCD/R7: J1.12; also elsewhere on the board
/LCD/VSYNC: J1.33; also elsewhere on the board
/LCD/XL_ADC: J1.39; also elsewhere on the board
/LCD/XR_ADC: J1.37; also elsewhere on the board
/LCD/YD_ADC: J1.38; also elsewhere on the board
/LCD/YU_ADC: J1.40; also elsewhere on the board
GND: J1.1, J1.3, J1.29, J1.36; also elsewhere on the board

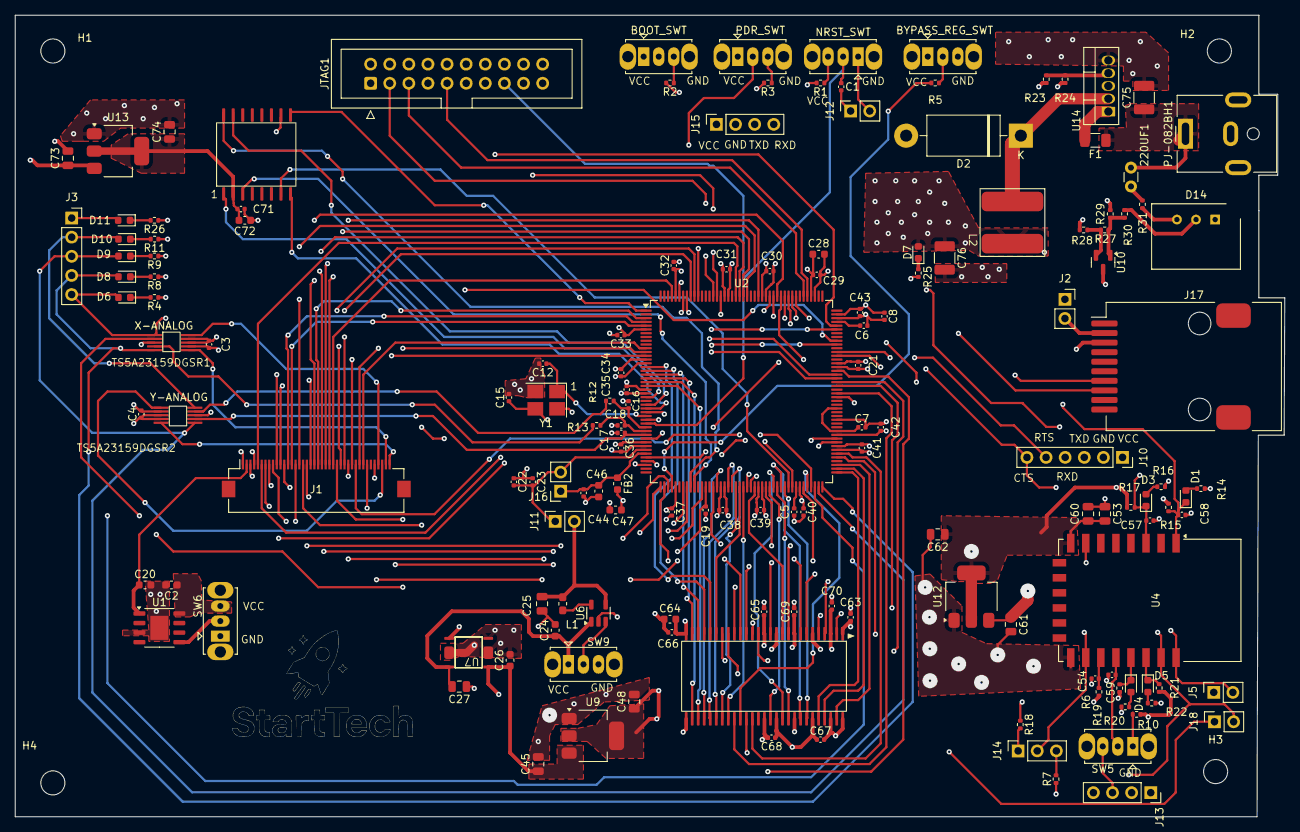
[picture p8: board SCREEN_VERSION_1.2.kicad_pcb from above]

Board: 6 copper layers, 168.7 x 106.5 mm, 154 parts (0 on the bottom side), 161 nets.

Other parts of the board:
BOOT_SWT: BOOT0_SWT; SW_Slide_SPDT_Straight_CK_OS102011MS2Q
BYPASS_REG_SWT: BYPASS_REG SWT; SW_Slide_SPDT_Straight_CK_OS102011MS2Q
NRST_SWT: NRST_SWT; SW_Slide_SPDT_Straight_CK_OS102011MS2Q
PDR_SWT: PDR_ON SWT; SW_Slide_SPDT_Straight_CK_OS102011MS2Q

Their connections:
3.3V: BOOT_SWT.1 (A), BYPASS_REG_SWT.1 (A), PDR_SWT.1 (A); also elsewhere on the board
/STM32F469IIT6/BOOT0: BOOT_SWT.2 (B); also elsewhere on the board
/STM32F469IIT6/BYPASS_REG: BYPASS_REG_SWT.2 (B); also elsewhere on the board
/STM32F469IIT6/NRST: NRST_SWT.2 (B); also elsewhere on the board
/STM32F469IIT6/PDR_ON: PDR_SWT.2 (B); also elsewhere on the board
GND: BYPASS_REG_SWT.3 (C); also elsewhere on the board
unnamed 137: NRST_SWT.1 (A); also elsewhere on the board
unnamed 140: BOOT_SWT.3 (C); also elsewhere on the board
unnamed 141: NRST_SWT.3 (C); also elsewhere on the board
unnamed 142: PDR_SWT.3 (C); also elsewhere on the board

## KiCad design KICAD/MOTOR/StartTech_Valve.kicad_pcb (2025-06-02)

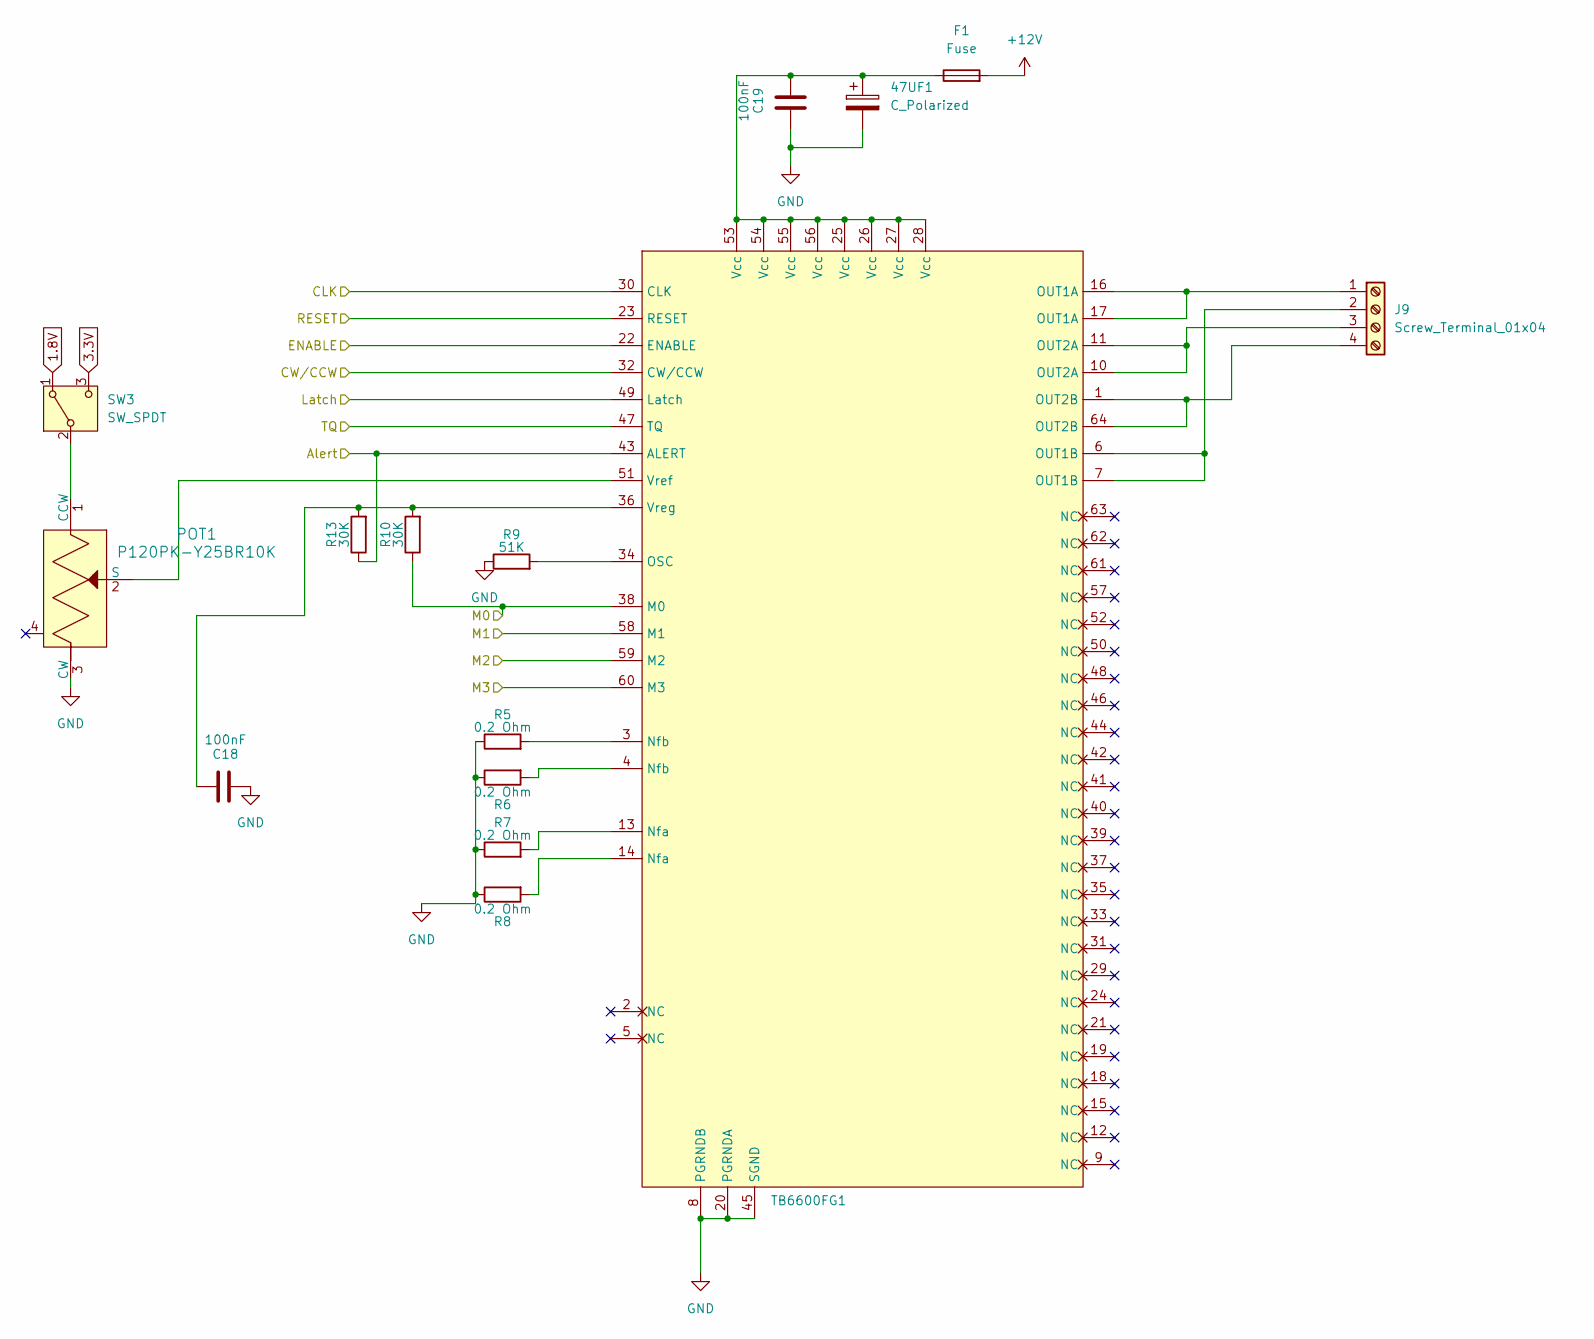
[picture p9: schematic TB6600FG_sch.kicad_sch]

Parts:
47UF1: C_Polarized; C_Disc_D3.0mm_W1.6mm_P2.50mm
C18, C19: 100nF; C_0402_1005Metric
F1: Fuse; Fuse_0402_1005Metric_Pad0.77x0.64mm_HandSolder
J9: Screw_Terminal_01x04; SCREWCON - 4PIN
POT1: P120PK-Y25BR10K; Potentiometer_P120PK-Y25BR10K; MPN P120PK-Y25BR10K; Digi-Key_PN 987-1710-ND
R5, R6, R7, R8: 0.2 Ohm; R_0402_1005Metric
R9: 51K; R_0402_1005Metric
R10, R13: 30K; R_0402_1005Metric
SW3: SW_SPDT; SW_Slide_SPDT_Straight_CK_OS102011MS2Q
TB6600FG1: TB6600FG

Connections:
1.8V: SW3.1 (A); also elsewhere on the board
3.3V: SW3.3 (C); also elsewhere on the board
+12V: F1.2; also elsewhere on the board
/STM32F411RCT6/Valve_ALERT: R13.1, TB6600FG1.43 (ALERT); also elsewhere on the board
/STM32F411RCT6/Valve_CCW: TB6600FG1.32 (CW/CCW); also elsewhere on the board
/STM32F411RCT6/Valve_CLK: TB6600FG1.30 (CLK); also elsewhere on the board
/STM32F411RCT6/Valve_EN: TB6600FG1.22 (ENABLE); also elsewhere on the board
/STM32F411RCT6/Valve_LATCH: TB6600FG1.49 (Latch); also elsewhere on the board
/STM32F411RCT6/Valve_M0: R10.1, TB6600FG1.38 (M0); also elsewhere on the board
/STM32F411RCT6/Valve_M1: TB6600FG1.58 (M1); also elsewhere on the board
/STM32F411RCT6/Valve_M2: TB6600FG1.59 (M2); also elsewhere on the board
/STM32F411RCT6/Valve_M3: TB6600FG1.60 (M3); also elsewhere on the board
/STM32F411RCT6/Valve_RST: TB6600FG1.23 (RESET); also elsewhere on the board
/STM32F411RCT6/Valve_TQ: TB6600FG1.47 (TQ); also elsewhere on the board
GND: 47UF1.2, C18.2, C19.1, POT1.3 (CW), R5.1, R6.1, R7.1, R8.1, R9.1, TB6600FG1.8 (PGRNDB), TB6600FG1.20 (PGRNDA), TB6600FG1.45 (SGND); also elsewhere on the board
unnamed: 47UF1.1, C19.2, F1.1, TB6600FG1.25 (Vcc), TB6600FG1.26 (Vcc), TB6600FG1.27 (Vcc), TB6600FG1.28 (Vcc), TB6600FG1.53 (Vcc), TB6600FG1.54 (Vcc), TB6600FG1.55 (Vcc), TB6600FG1.56 (Vcc)
unnamed: J9.1, TB6600FG1.16 (OUT1A), TB6600FG1.17 (OUT1A)
unnamed: J9.2, TB6600FG1.6 (OUT1B), TB6600FG1.7 (OUT1B)
unnamed: J9.3, TB6600FG1.10 (OUT2A), TB6600FG1.11 (OUT2A)
unnamed: J9.4, TB6600FG1.1 (OUT2B), TB6600FG1.64 (OUT2B)
unnamed: POT1.1 (CCW), SW3.2 (B)
unnamed: POT1.2 (S), TB6600FG1.51 (Vref)
unnamed: R5.2, TB6600FG1.3 (Nfb)
unnamed: R6.2, TB6600FG1.4 (Nfb)
unnamed: R7.2, TB6600FG1.13 (Nfa)
unnamed: R8.2, TB6600FG1.14 (Nfa)
unnamed: R9.2, TB6600FG1.34 (OSC)
unnamed: C18.1, R10.2, R13.2, TB6600FG1.36 (Vreg)

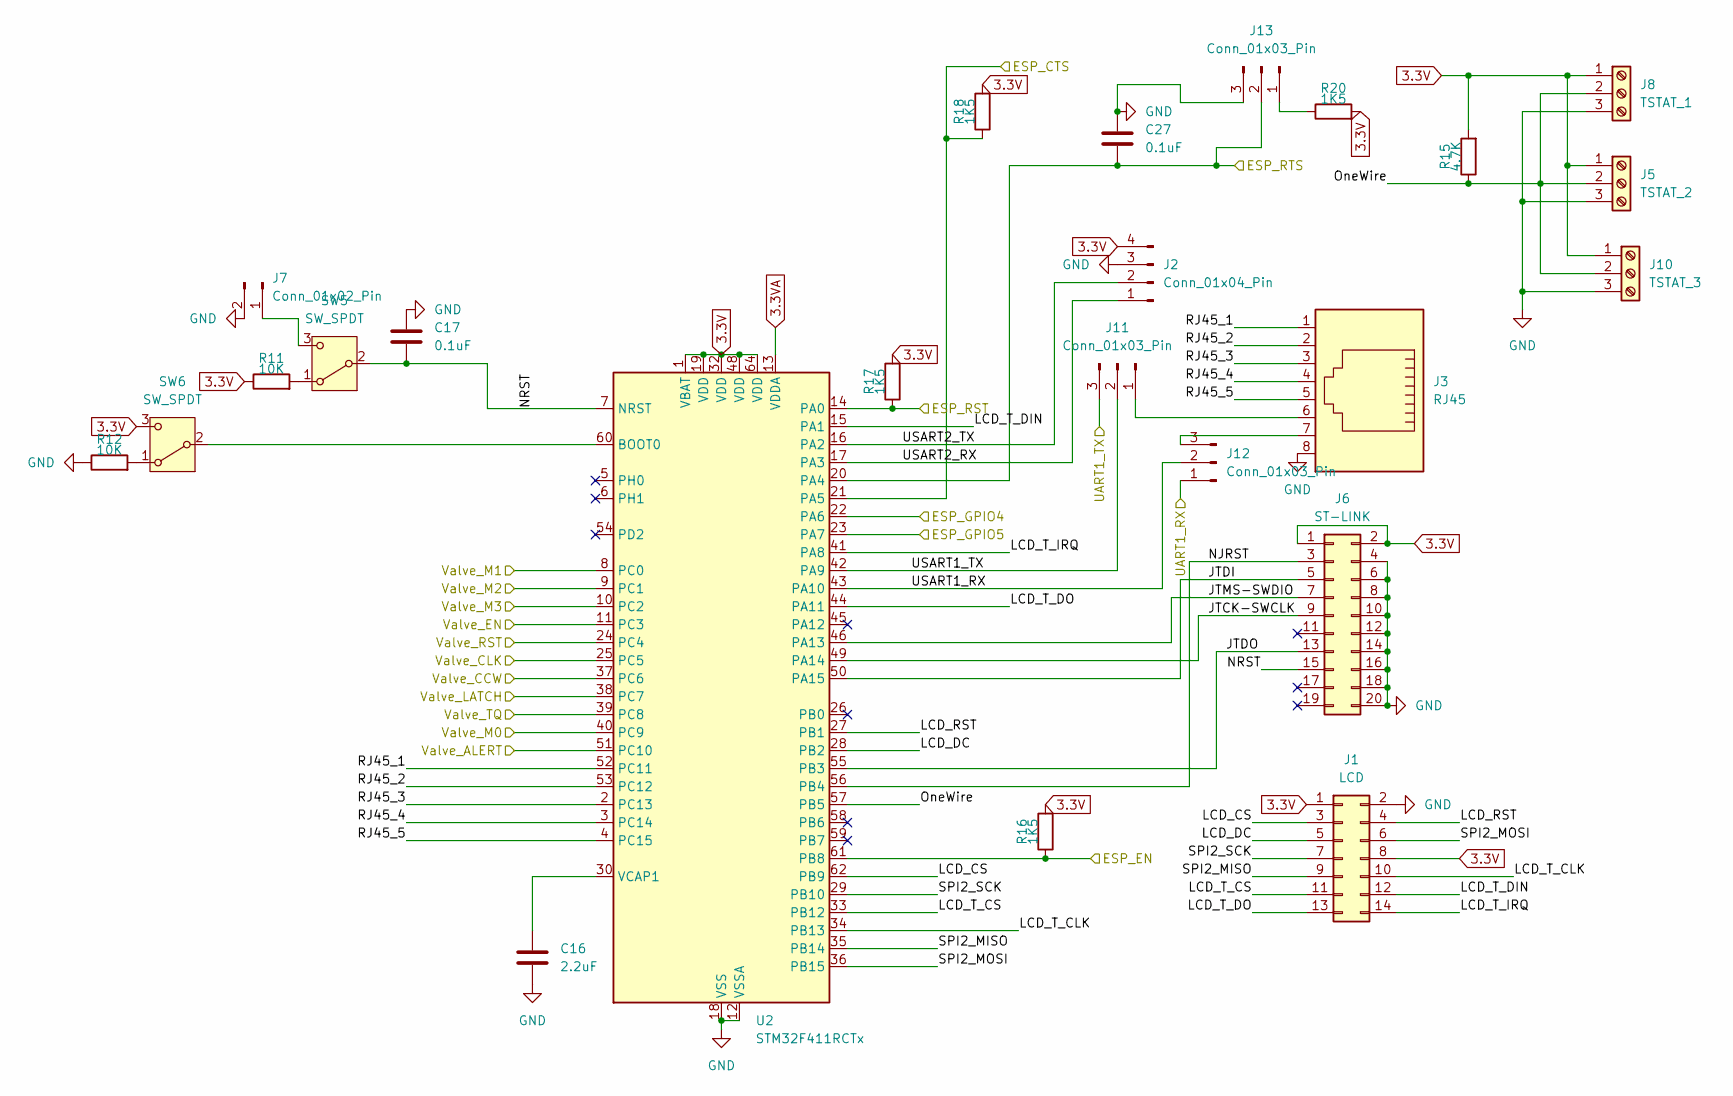
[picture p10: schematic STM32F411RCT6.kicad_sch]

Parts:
C16: 2.2uF; C_0603_1608Metric
C17, C27: 0.1uF; C_0402_1005Metric
J1: LCD; IDC-Header_2x07_P2.54mm_Vertical
J2: Conn_01x04_Pin; PinSocket_1x04_P2.54mm_Vertical
J3: RJ45; RJ45_Cetus_J1B1211CCD_Horizontal
J5: TSTAT_2; SCREWCON-3PIN
J6: ST-LINK; IDC-Header_2x10_P2.54mm_Vertical
J7: Conn_01x02_Pin; PinSocket_1x02_P2.54mm_Vertical
J8: TSTAT_1; SCREWCON-3PIN
J10: TSTAT_3; SCREWCON-3PIN
J11, J12, J13: Conn_01x03_Pin; PinSocket_1x03_P2.54mm_Vertical
R11, R12: 10K; R_0402_1005Metric
R15: 4.7K; R_0402_1005Metric
R16, R17, R18, R20: 1K5; R_0402_1005Metric
SW5, SW6: SW_SPDT; SW_Slide_SPDT_Straight_CK_OS102011MS2Q
U2: STM32F411RCTx; LQFP-64_10x10mm_P0.5mm

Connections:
3.3V: J1.1, J1.8, J2.4, J5.1, J6.1, J6.2, J8.1, J10.1, R11.1, R15.2, R16.2, R17.2, R18.2, R20.2, SW6.3 (C), U2.1 (VBAT), U2.19 (VDD), U2.32 (VDD), U2.48 (VDD), U2.64 (VDD); also elsewhere on the board
3.3VA: U2.13 (VDDA); also elsewhere on the board
/ESP-12E/CTS: R18.1, U2.21 (PA5); also elsewhere on the board
/ESP-12E/EN: R16.1, U2.61 (PB8); also elsewhere on the board
/ESP-12E/IO4: U2.22 (PA6); also elsewhere on the board
/ESP-12E/IO5: U2.23 (PA7); also elsewhere on the board
/ESP-12E/RST: R17.1, U2.14 (PA0); also elsewhere on the board
/ESP-12E/RTS: C27.2, J13.2, U2.20 (PA4); also elsewhere on the board
/ESP-12E/RXD: J11.3; also elsewhere on the board
/ESP-12E/TXD: J12.1; also elsewhere on the board
/STM32F411RCT6/JTCK-SWCLK: J6.9, U2.49 (PA14)
/STM32F411RCT6/JTDI: J6.5, U2.50 (PA15)
/STM32F411RCT6/JTDO: J6.13, U2.55 (PB3)
/STM32F411RCT6/JTMS-SWDIO: J6.7, U2.46 (PA13)
/STM32F411RCT6/LCD_CS: J1.3, U2.62 (PB9)
/STM32F411RCT6/LCD_DC: J1.5, U2.28 (PB2)
/STM32F411RCT6/LCD_RST: J1.4, U2.27 (PB1)
/STM32F411RCT6/LCD_T_CLK: J1.10, U2.34 (PB13)
/STM32F411RCT6/LCD_T_CS: J1.11, U2.33 (PB12)
/STM32F411RCT6/LCD_T_DIN: J1.12, U2.15 (PA1)
/STM32F411RCT6/LCD_T_DO: J1.13, U2.44 (PA11)
/STM32F411RCT6/LCD_T_IRQ: J1.14, U2.41 (PA8)
/STM32F411RCT6/NJRST: J6.3, U2.56 (PB4)
/STM32F411RCT6/NRST: C17.2, J6.15, SW5.2 (B), U2.7 (NRST)
/STM32F411RCT6/OneWire: J5.2, J8.2, J10.2, R15.1, U2.57 (PB5)
/STM32F411RCT6/RJ45_1: J3.1, U2.52 (PC11)
/STM32F411RCT6/RJ45_2: J3.2, U2.53 (PC12)
/STM32F411RCT6/RJ45_3: J3.3, U2.2 (PC13)
/STM32F411RCT6/RJ45_4: J3.4, U2.3 (PC14)
/STM32F411RCT6/RJ45_5: J3.5, U2.4 (PC15)
/STM32F411RCT6/SPI2_MISO: J1.9, U2.35 (PB14)
/STM32F411RCT6/SPI2_MOSI: J1.6, U2.36 (PB15)
/STM32F411RCT6/SPI2_SCK: J1.7, U2.29 (PB10)
/STM32F411RCT6/USART1_RX: J12.2, U2.43 (PA10)
/STM32F411RCT6/USART1_TX: J11.2, U2.42 (PA9)
/STM32F411RCT6/USART2_RX: J2.1, U2.17 (PA3)
/STM32F411RCT6/USART2_TX: J2.2, U2.16 (PA2)
/STM32F411RCT6/Valve_ALERT: U2.51 (PC10); also elsewhere on the board
/STM32F411RCT6/Valve_CCW: U2.37 (PC6); also elsewhere on the board
/STM32F411RCT6/Valve_CLK: U2.25 (PC5); also elsewhere on the board
/STM32F411RCT6/Valve_EN: U2.11 (PC3); also elsewhere on the board
/STM32F411RCT6/Valve_LATCH: U2.38 (PC7); also elsewhere on the board
/STM32F411RCT6/Valve_M0: U2.40 (PC9); also elsewhere on the board
/STM32F411RCT6/Valve_M1: U2.8 (PC0); also elsewhere on the board
/STM32F411RCT6/Valve_M2: U2.9 (PC1); also elsewhere on the board
/STM32F411RCT6/Valve_M3: U2.10 (PC2); also elsewhere on the board
/STM32F411RCT6/Valve_RST: U2.24 (PC4); also elsewhere on the board
/STM32F411RCT6/Valve_TQ: U2.39 (PC8); also elsewhere on the board
GND: C16.2, C17.1, C27.1, J1.2, J2.3, J3.8, J5.3, J6.4, J6.6, J6.8, J6.10, J6.12, J6.14, J6.16, J6.18, J6.20, J7.2, J8.3, J10.3, J13.3, R12.1, U2.12 (VSSA), U2.18 (VSS), U2.31 (VSS), U2.47 (VSS), U2.63 (VSS); also elsewhere on the board
unnamed: J7.1, SW5.3 (C)
unnamed: J3.6, J11.1
unnamed: J3.7, J12.3
unnamed: J13.1, R20.1
unnamed: R11.2, SW5.1 (A)
unnamed: R12.2, SW6.1 (A)
unnamed: SW6.2 (B), U2.60 (BOOT0)
unnamed: C16.1, U2.30 (VCAP1)

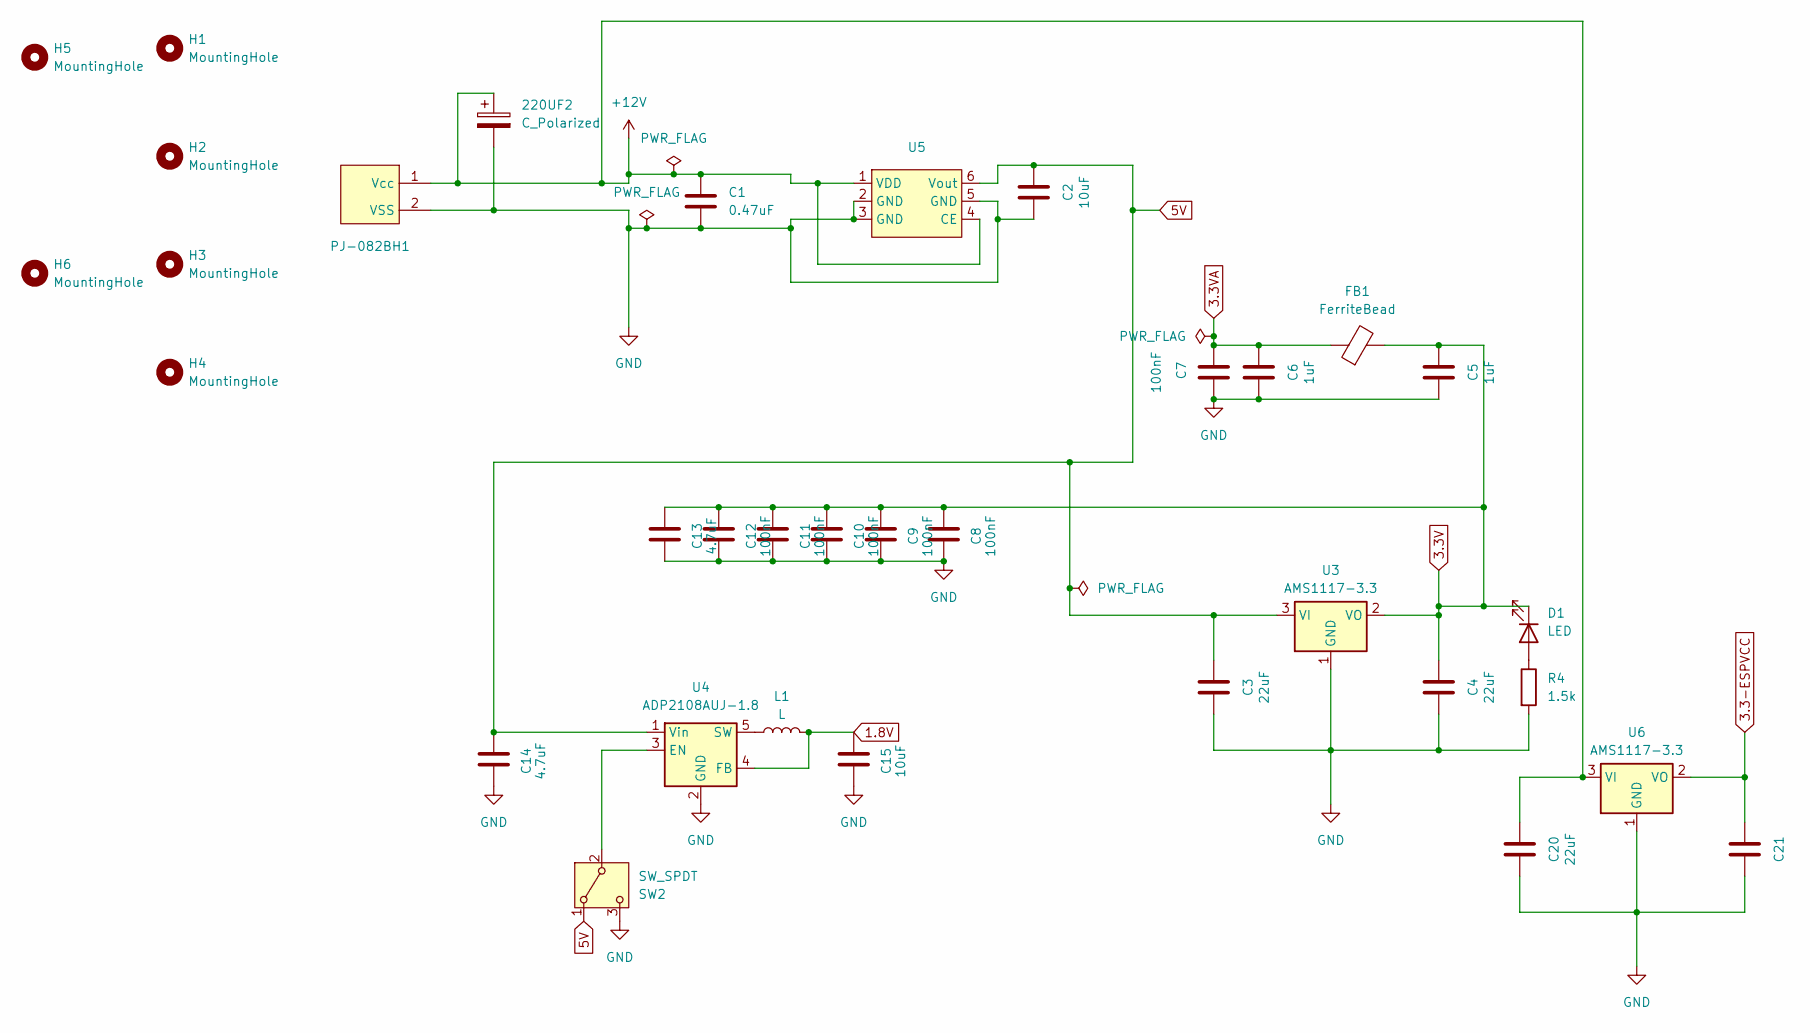
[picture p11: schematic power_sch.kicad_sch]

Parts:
220UF2: C_Polarized; C_Disc_D3.0mm_W1.6mm_P2.50mm
C1: 0.47uF; C_0603_1608Metric
C2, C15: 10uF; C_0805_2012Metric
C3, C4, C20, C21: 22uF; C_0805_2012Metric
C5, C6: 1uF; C_0603_1608Metric
C7, C8, C9, C10, C11, C12: 100nF; C_0402_1005Metric
C13, C14: 4.7uF; C_0603_1608Metric
D1: LED; LED_0603_1608Metric
FB1: FerriteBead; L_0603_1608Metric
H1, H2, H3, H4, H5, H6: MountingHole; MountingHole_3.2mm_M3_DIN965
L1: L; L_0603_1608Metric_Pad1.05x0.95mm_HandSolder
PJ-082BH1: BarrelJack_CUI_PJ-063AH_Horizontal
R4: 1.5k; R_0402_1005Metric
SW2: SW_SPDT; SW_Slide_SPDT_Straight_CK_OS102011MS2Q
U3, U6: AMS1117-3.3; SOT-223-3_TabPin2
U4: ADP2108AUJ-1.8; TSOT-23-5
U5: R1501S050B-E2-FE

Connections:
1.8V: C15.1, L1.2, U4.4 (FB); also elsewhere on the board
3.3-ESPVCC: C21.2, U6.2 (VO); also elsewhere on the board
3.3V: C4.2, C5.2, C8.1, C9.1, C10.1, C11.1, C12.1, C13.1, D1.1 (K), FB1.2, U3.2 (VO); also elsewhere on the board
3.3VA: C6.2, C7.2, FB1.1; also elsewhere on the board
5V: C2.2, C3.2, C14.1, SW2.1 (A), U3.3 (VI), U4.1 (Vin), U5.6 (Vout)
+12V: 220UF2.1, C1.1, C20.2, PJ-082BH1.1 (Vcc), U5.1 (VDD), U5.4 (CE), U6.3 (VI); also elsewhere on the board
GND: 220UF2.2, C1.2, C2.1, C3.1, C4.1, C5.1, C6.1, C7.1, C8.2, C9.2, C10.2, C11.2, C12.2, C13.2, C14.2, C15.2, C20.1, C21.1, PJ-082BH1.2 (VSS), R4.2, SW2.3 (C), U3.1 (GND), U4.2 (GND), U5.2 (GND), U5.3 (GND), U5.5 (GND), U6.1 (GND); also elsewhere on the board
unnamed: D1.2 (A), R4.1
unnamed: SW2.2 (B), U4.3 (EN)
unnamed: L1.1, U4.5 (SW)

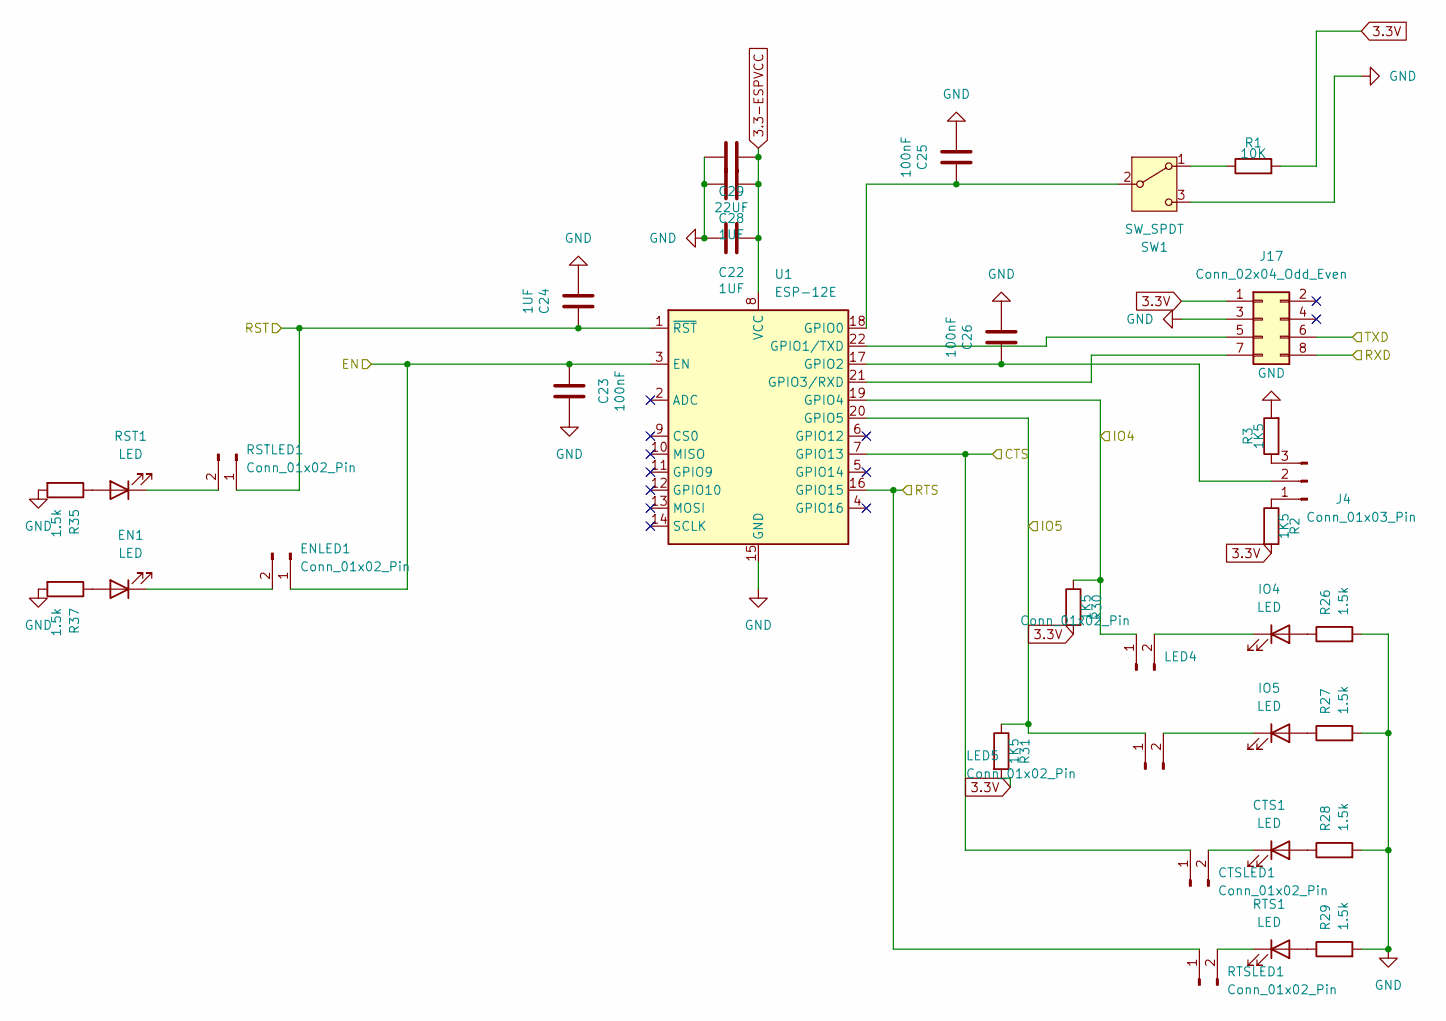
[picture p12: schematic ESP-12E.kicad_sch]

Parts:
C22, C24, C28: 1UF; C_0805_2012Metric
C23, C25, C26: 100nF; C_0805_2012Metric
C29: 22UF; C_0805_2012Metric
CTS1: LED; LED_0603_1608Metric
CTSLED1: Conn_01x02_Pin; PinSocket_1x02_P2.54mm_Vertical
EN1: LED; LED_0603_1608Metric
ENLED1: Conn_01x02_Pin; PinSocket_1x02_P2.54mm_Vertical
IO4, IO5: LED; LED_0603_1608Metric
J4: Conn_01x03_Pin; PinSocket_1x03_P2.54mm_Vertical
J17: Conn_02x04_Odd_Even; PinSocket_2x04_P2.54mm_Vertical
LED4, LED5: Conn_01x02_Pin; PinSocket_1x02_P2.54mm_Vertical
R1: 10K; R_0402_1005Metric
R2, R3, R30, R31: 1K5; R_0402_1005Metric
R26, R27, R28, R29, R35, R37: 1.5k; R_0402_1005Metric
RST1: LED; LED_0603_1608Metric
RSTLED1: Conn_01x02_Pin; PinSocket_1x02_P2.54mm_Vertical
RTS1: LED; LED_0603_1608Metric
RTSLED1: Conn_01x02_Pin; PinSocket_1x02_P2.54mm_Vertical
SW1: SW_SPDT; SW_Slide_SPDT_Straight_CK_OS102011MS2Q
U1: ESP-12E

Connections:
3.3-ESPVCC: C22.2, C28.2, C29.2, U1.8 (VCC); also elsewhere on the board
3.3V: J17.1, R1.2, R2.2, R30.2, R31.2; also elsewhere on the board
/ESP-12E/CTS: CTSLED1.1, U1.7 (GPIO13); also elsewhere on the board
/ESP-12E/EN: C23.2, ENLED1.1, U1.3 (EN); also elsewhere on the board
/ESP-12E/IO4: LED4.1, R30.1, U1.19 (GPIO4); also elsewhere on the board
/ESP-12E/IO5: LED5.1, R31.1, U1.20 (GPIO5); also elsewhere on the board
/ESP-12E/RST: C24.2, RSTLED1.1, U1.1 (~RST); also elsewhere on the board
/ESP-12E/RTS: RTSLED1.1, U1.16 (GPIO15); also elsewhere on the board
/ESP-12E/RXD: J17.8; also elsewhere on the board
/ESP-12E/TXD: J17.6; also elsewhere on the board
GND: C22.1, C23.1, C24.1, C25.1, C26.1, C28.1, C29.1, J17.3, R3.2, R26.2, R27.2, R28.2, R29.2, R35.2, R37.2, SW1.3 (C), U1.15 (GND); also elsewhere on the board
unnamed: CTS1.2 (A), R28.1
unnamed: CTS1.1 (K), CTSLED1.2
unnamed: EN1.2 (A), R37.1
unnamed: EN1.1 (K), ENLED1.2
unnamed: IO4.2 (A), R26.1
unnamed: IO4.1 (K), LED4.2
unnamed: IO5.2 (A), R27.1
unnamed: IO5.1 (K), LED5.2
unnamed: J4.1, R2.1
unnamed: C26.2, J4.2, U1.17 (GPIO2)
unnamed: J4.3, R3.1
unnamed: J17.5, U1.22 (GPIO1/TXD)
unnamed: J17.7, U1.21 (GPIO3/RXD)
unnamed: R35.1, RST1.2 (A)
unnamed: RST1.1 (K), RSTLED1.2
unnamed: R29.1, RTS1.2 (A)
unnamed: RTS1.1 (K), RTSLED1.2
unnamed: R1.1, SW1.1 (A)
unnamed: C25.2, SW1.2 (B), U1.18 (GPIO0)


Board: 4 copper layers, 155.4 x 116.3 mm, 107 parts (0 on the bottom side), 96 nets.

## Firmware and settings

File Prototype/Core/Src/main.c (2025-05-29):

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
/* Includes ------------------------------------------------------------------*/
#include "main.h"
#include "cmsis_os.h"

/* USER CODE BEGIN Includes */
#include<stdlib.h>
#include<stdio.h>
#include<string.h>
#include<stdbool.h>
#include <stdint.h>
#include <serial_printing.h>
#include "GUI.h"
#include "types.h"
#include "touch.h"
#include "control.h"

// Initialize the framebuffer to a specific color, e.g., 0xFFFF (white in RGB565)

/*static const uint8_t framebuffer[FRAMEBUFFER_SIZE] = {
    [0 ... FRAMEBUFFER_SIZE - 1] = color_index  // GNU C extension to initialize all elements
};*/ /*780 x 400*/
uint32_t adcs[2] = {0};
/* USER CODE END Includes */

/* USER CODE BEGIN PD */
volatile uint8_t uart8_tx_complete = 0;
/* USER CODE END PD */

ADC_HandleTypeDef hadc1;
DMA_HandleTypeDef hdma_adc1;

LTDC_HandleTypeDef hltdc;

QSPI_HandleTypeDef hqspi;

SPI_HandleTypeDef hspi2;

UART_HandleTypeDef huart4;
UART_HandleTypeDef huart5;
UART_HandleTypeDef huart8;

SDRAM_HandleTypeDef hsdram1;

/* Definitions for mainTask */
osThreadId_t mainTaskHandle;
const osThreadAttr_t mainTask_attributes = {
  .name = "mainTask",
  .stack_size = 128 * 4,
  .priority = (osPriority_t) osPriorityNormal,
};
/* Definitions for lcdTask */
osThreadId_t lcdTaskHandle;
const osThreadAttr_t lcdTask_attributes = {
  .name = "lcdTask",
  .stack_size = 128 * 4,
  .priority = (osPriority_t) osPriorityLow,
};
/* Definitions for adcTask */
osThreadId_t adcTaskHandle;
const osThreadAttr_t adcTask_attributes = {
  .name = "adcTask",
  .stack_size = 128 * 4,
  .priority = (osPriority_t) osPriorityLow,
};
/* Definitions for lcd_task */
osThreadId_t lcd_taskHandle;
const osThreadAttr_t lcd_task_attributes = {
  .name = "lcd_task",
  .stack_size = 128 * 4,
  .priority = (osPriority_t) osPriorityLow,
};
/* Definitions for mainMutexHandle */
osMutexId_t mainMutexHandleHandle;
const osMutexAttr_t mainMutexHandle_attributes = {
  .name = "mainMutexHandle"
};
/* Definitions for adcControllerMutex */
osMutexId_t adcControllerMutexHandle;
const osMutexAttr_t adcControllerMutex_attributes = {
  .name = "adcControllerMutex"
};
/* Definitions for lcdControllerMutex */
osMutexId_t lcdControllerMutexHandle;
const osMutexAttr_t lcdControllerMutex_attributes = {
  .name = "lcdControllerMutex"
};
/* Definitions for uartControllerMutex */
osMutexId_t uartControllerMutexHandle;
const osMutexAttr_t uartControllerMutex_attributes = {
  .name = "uartControllerMutex"
};
/* Definitions for adcMutex */
osMutexId_t adcMutexHandle;
const osMutexAttr_t adcMutex_attributes = {
  .name = "adcMutex"
};
/* Definitions for uartMutex */
osMutexId_t uartMutexHandle;
const osMutexAttr_t uartMutex_attributes = {
  .name = "uartMutex"
};
/* Definitions for lcdMutex */
osMutexId_t lcdMutexHandle;
const osMutexAttr_t lcdMutex_attributes = {
  .name = "lcdMutex"
};
/* USER CODE BEGIN PV */
__IO uint16_t uhADCxConvertedValue = 0;
uint8_t         ubAnalogWatchdogStatus = RESET;

ADC_ChannelConfTypeDef sConfig = {0};
GPIO_InitTypeDef GPIO_InitStruct = {0};

/* USER CODE END PV */

void SystemClock_Config(void);
static void MX_GPIO_Init(void);
static void MX_DMA_Init(void);
static void MX_LTDC_Init(void);
static void MX_FMC_Init(void);
static void MX_ADC1_Init(void);
static void MX_QUADSPI_Init(void);
static void MX_SPI2_Init(void);
static void MX_UART4_Init(void);
static void MX_UART8_Init(void);
static void MX_UART5_Init(void);
void mainFunction(void *argument);
void uartFunction(void *argument);
void adcFunction(void *argument);
void lcd_function(void *argument);

/* USER CODE BEGIN PFP */
void RESTORE_ADC();
/* USER CODE END PFP */

/* USER CODE BEGIN 0 */


char rxBuffer[1024];
uint8_t flag = 0x00;
char uartBuffer[1024] = {};
uint16_t *BUFFER_LAYER_1;
uint16_t *BUFFER_LAYER_2;
uint32_t ADC_THREAD_CONTROL_BIT;
uint32_t UART_THREAD_CONTROL_BIT;
uint32_t LCD_THREAD_CONTROL_BIT;

uint32_t MAIN_THREAD_ADC_CONTROL_BIT;
uint32_t MAIN_THREAD_UART_CONTROL_BIT;
uint32_t MAIN_THREAD_LCD_CONTROL_BIT;

DATA_HOLDER mainDataHolder;
DATA_HOLDER lcdDataHolder;

CMD cmd = {
		.origin = {0},
		.protocol = {0},
		.command = {0},
		.args = {0},
		.cmd_all = {0},
		.cmd_all_tmp = {0},
		.cmd_flag = 0x00,
		.status_busy = false
};

Button button = {
		  .c = {0},
		  .data = 25,
		  .n = 0,
		  .rst = false,
		  .set = false,
		  .temp_set = 0,
		  .valid = false,
		  .value = 0
};
Pressed pressed = {
		  .X_ = 0,
		  .Y_=0
};
char msg2[100];
/* USER CODE END 0 */

/**
  * @brief  The application entry point.
  * @retval int
  */
int main(void)
{

  /* USER CODE BEGIN 1 */
	strcpy(mainDataHolder.callingWaterTemp, "calling");
	strcpy(mainDataHolder.hotWaterTemp, "hot");
	strcpy(mainDataHolder.motor_position, "motor");
	strcpy(mainDataHolder.showerWaterTemp, "shower");

	lcdDataHolder.setTemp = 25;
	//uint16_t *BUFFER_LAYER_1 = (uint16_t *)BUFFER_LAYER_1_ADDRESS;
	//uint16_t *BUFFER_LAYER_2 = (uint16_t *)BUFFER_LAYER_2_ADDRESS;

    //HAL_SDRAM_Write_16b(&hsdram1, (uint32_t *)BUFFER_LAYER_1, (uint16_t *)RGB565_Dark_sky_blue, FRAMEBUFFER_WIDTH * FRAMEBUFFER_HEIGHT);


  /* USER CODE END 1 */

  /* MCU Configuration--------------------------------------------------------*/

  /* Reset of all peripherals, Initializes the Flash interface and the Systick. */
  HAL_Init();

  /* Configure the system clock */
  SystemClock_Config();

  /* Initialize all configured peripherals */
  MX_GPIO_Init();
  MX_DMA_Init();
  MX_LTDC_Init();
  MX_FMC_Init();
  MX_ADC1_Init();
  MX_QUADSPI_Init();
  MX_SPI2_Init();
  MX_UART4_Init();
  MX_UART8_Init();
  MX_UART5_Init();
  /* USER CODE BEGIN 2 */

  /* Infinite loop */
	// Allocate buffer

	  int y_ = 0;

	  uint16_t yellow_rgb565 = RGB565_Solid_pink;
	  for (int y = 0; y < FRAMEBUFFER_HEIGHT; y++) {
	          for (int x = 0; x < FRAMEBUFFER_WIDTH; x++) {
	        	  uint32_t index = y * FRAMEBUFFER_WIDTH + x; // 1D index
	        	  uint32_t address = (uint32_t)BUFFER_LAYER_1_ADDRESS + index * BYTES_PER_PIXEL; // SDRAM address
	              HAL_SDRAM_Write_16b(&hsdram1, (uint32_t *)address, &yellow_rgb565, 1);
	              address += BYTES_PER_PIXEL; // Increment by 2 bytes for each pixel
	          }
	      }
	  HAL_Delay(1000);

	//LCD_Fill(BUFFER_LAYER_1_ADDRESS, 0, 0,FRAMEBUFFER_WIDTH,FRAMEBUFFER_HEIGHT,RGB565_Celtic_blue);
	ESP_RST_GPIO_Port->BSRR = 1U << (4+16);
	ESP_EN_GPIO_Port->BSRR = 1U << (5+16);
	HAL_Delay(1000);
	ESP_RST_GPIO_Port->BSRR = 1U << (4);
	ESP_EN_GPIO_Port->BSRR = 1U << 5;

	//sprintf(msg2, "JUST GOT HERE 7\n");
	//HAL_UART_Transmit(&huart8, (uint8_t *)msg2, strlen(msg2), 1000);

	//draw_terminal(BUFFER_LAYER_1_ADDRESS);
	//keypad(BUFFER_LAYER_1_ADDRESS);
	//draw_futuristic_background(BUFFER_LAYER_1_ADDRESS);
	PAGE_HOME_INIT_VAR();
	PAGE_HOME_Draw(BUFFER_LAYER_1_ADDRESS);
	ESP_RTS_GPIO_Port->BSRR = 1U << (8+16);
	//ESP_RTS_GPIO_Port->BSRR = 1U << (8);
	GPIOC->BSRR = 1U << 2; // YD
	//char msg1[100] = "RUN 2 200";

  /* USER CODE END 2 */

  /* Init scheduler */
  osKernelInitialize();
  /* Create the mutex(es) */
  /* creation of mainMutexHandle */
  mainMutexHandleHandle = osMutexNew(&mainMutexHandle_attributes);

  /* creation of adcControllerMutex */
  adcControllerMutexHandle = osMutexNew(&adcControllerMutex_attributes);

  /* creation of lcdControllerMutex */
  lcdControllerMutexHandle = osMutexNew(&lcdControllerMutex_attributes);

  /* creation of uartControllerMutex */
  uartControllerMutexHandle = osMutexNew(&uartControllerMutex_attributes);

  /* creation of adcMutex */
  adcMutexHandle = osMutexNew(&adcMutex_attributes);

  /* creation of uartMutex */
  uartMutexHandle = osMutexNew(&uartMutex_attributes);

  /* creation of lcdMutex */
  lcdMutexHandle = osMutexNew(&lcdMutex_attributes);

  /* USER CODE BEGIN RTOS_MUTEX */
  /* add mutexes, ... */
  /* USER CODE END RTOS_MUTEX */

  /* USER CODE BEGIN RTOS_SEMAPHORES */
  /* add semaphores, ... */
  /* USER CODE END RTOS_SEMAPHORES */

  /* USER CODE BEGIN RTOS_TIMERS */
  /* start timers, add new ones, ... */
  /* USER CODE END RTOS_TIMERS */

  /* USER CODE BEGIN RTOS_QUEUES */
  /* add queues, ... */
  /* USER CODE END RTOS_QUEUES */

  /* Create the thread(s) */
  /* creation of mainTask */
  mainTaskHandle = osThreadNew(mainFunction, NULL, &mainTask_attributes);

  /* creation of lcdTask */
  lcdTaskHandle = osThreadNew(uartFunction, NULL, &lcdTask_attributes);

  /* creation of adcTask */
  adcTaskHandle = osThreadNew(adcFunction, NULL, &adcTask_attributes);

  /* creation of lcd_task */
  lcd_taskHandle = osThreadNew(lcd_function, NULL, &lcd_task_attributes);

  /* USER CODE BEGIN RTOS_THREADS */
  /* add threads, ... */
  /* USER CODE END RTOS_THREADS */

  /* USER CODE BEGIN RTOS_EVENTS */
  /* add events, ... */
  /* USER CODE END RTOS_EVENTS */

  /* Start scheduler */
  osKernelStart();

  /* We should never get here as control is now taken by the scheduler */

  /* Infinite loop */
  /* USER CODE BEGIN WHILE */
	//memset(adcReadings, 0, sizeof(adcReadings));
    //HAL_ADC_Start_DMA(&hadc1, (uint32_t *)adcReadings, 1000);
  while (1)
  {
    /* USER CODE END WHILE */

    /* USER CODE BEGIN 3 */
	  //HAL_SDRAM_Read_8b(&hsdram1, (uint32_t *)BUFFER_LAYER_1, (uint8_t *)myReadData, 4);
	// Reconfigure ADC to use the correct input channel (e.g., ADC_CHANNEL_9 on PB1)
	RESTORE_ADC();
	HAL_ADC_Start(&hadc1);
	if (HAL_ADC_PollForConversion(&hadc1, 10) == HAL_OK) {
		y_ = HAL_ADC_GetValue(&hadc1);
		HAL_ADC_Stop(&hadc1);
		if (y_ > 2500) {
			ESP_RTS_GPIO_Port->BSRR = 1U << (8+16);
			scan_(BUFFER_LAYER_1_ADDRESS);
			HAL_Delay(500);
			if (HAL_ADC_Init(&hadc1) != HAL_OK) Error_Handler();
			ESP_RTS_GPIO_Port->BSRR = 1U << (8);
		}
	} else {
		printf_(BUFFER_LAYER_1_ADDRESS, "ADC timeout");
	}

	if(cmd.status_busy == true){
		char *cmdmsg = "BUSY TRUE";
		printf_(BUFFER_LAYER_1_ADDRESS, cmdmsg);
	}
	CMD_HANDLER(BUFFER_LAYER_1_ADDRESS);
	//printf_(buffer2, myReadData);
  }
  /* USER CODE END 3 */
}

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
/* USER CODE BEGIN 4 */

void RESTORE_ADC(){
	ADC_ChannelConfTypeDef sConfig = {0};
	GPIO_InitTypeDef GPIO_InitStruct = {0};

	GPIO_InitStruct.Pin = GPIO_PIN_2;
	GPIO_InitStruct.Mode = GPIO_MODE_OUTPUT_PP;
	HAL_GPIO_Init(GPIOC, &GPIO_InitStruct);
	HAL_GPIO_WritePin(GPIOC, GPIO_PIN_2, GPIO_PIN_SET);

	GPIO_InitStruct.Pin = GPIO_PIN_0;
	HAL_GPIO_Init(GPIOC, &GPIO_InitStruct);
	HAL_GPIO_WritePin(GPIOC, GPIO_PIN_0, GPIO_PIN_RESET);

	GPIO_InitStruct.Pin = GPIO_PIN_1;
	GPIO_InitStruct.Mode = GPIO_MODE_ANALOG;
	HAL_GPIO_Init(GPIOC, &GPIO_InitStruct);

	GPIO_InitStruct.Pin = GPIO_PIN_1;
	HAL_GPIO_Init(GPIOB, &GPIO_InitStruct);

	osDelay(10);

	sConfig.Channel = ADC_CHANNEL_9;
	sConfig.Rank = 1;
	sConfig.SamplingTime = ADC_SAMPLETIME_480CYCLES;
	HAL_ADC_ConfigChannel(&hadc1, &sConfig);
}


// DMA Transfer Complete Callback
void HAL_UART_TxCpltCallback(UART_HandleTypeDef *huart)
{
  if (huart->Instance == UART8) // Check if it's the UART8 transfer
  {
    uart8_tx_complete = 1;
  }
}
/* USER CODE END 4 */

/* USER CODE BEGIN Header_mainFunction */
/**
  * @brief  Function implementing the mainTask thread.
  * @param  argument: Not used
  * @retval None
  */
/* USER CODE END Header_mainFunction */
void mainFunction(void *argument)
{
  /* USER CODE BEGIN 5 */
  /* Infinite loop */
  for(;;)
  {
	char msg8[100];
	sprintf(msg8,"Main Function  ###### MAIN #####\n");


	HAL_UART_Transmit(&huart8, (uint8_t *)msg8, strlen(msg8), 1000);
    osDelay(500);
  }
  /* USER CODE END 5 */
}

/* USER CODE BEGIN Header_uartFunction */
/**
* @brief Function implementing the lcdTask thread.
* @param argument: Not used
* @retval None
*/
/* USER CODE END Header_uartFunction */
void uartFunction(void *argument)
{
  /* USER CODE BEGIN uartFunction */
  /* Infinite loop */
  for(;;)
  {	char msg8[100];
	sprintf(msg8,"Uart Function  ###### UART #####\n");
	HAL_UART_Transmit(&huart8, (uint8_t *)msg8, strlen(msg8), 1000);
    osDelay(200);
  }
  /* USER CODE END uartFunction */
}

/* USER CODE BEGIN Header_adcFunction */
/**
* @brief Function implementing the adcTask thread.
* @param argument: Not used
* @retval None
*/
/* USER CODE END Header_adcFunction */
void adcFunction(void *argument)
{
  /* USER CODE BEGIN adcFunction */
  int y_;
  /* Infinite loop */
  for(;;)
  {	char msg8[100];
	sprintf(msg8,"ADC Function  ###### ADC #####\n");
	HAL_UART_Transmit(&huart8, (uint8_t *)msg8, strlen(msg8), 1000);

	RESTORE_ADC(); // Restore ADC to its starting condition
	HAL_ADC_Start(&hadc1); // Start ADC based on starting condition
	if (HAL_ADC_PollForConversion(&hadc1, 10) == HAL_OK) { // Read ADC in Polling Mode
		y_ = HAL_ADC_GetValue(&hadc1); // Get Value stored in ADC register
		HAL_ADC_Stop(&hadc1); // Stop Conversion
		if (y_ > 2500) { // Check Reading to identify if it was touched
			scan_(BUFFER_LAYER_1_ADDRESS);
			osDelay(100);

			if (HAL_ADC_Init(&hadc1) != HAL_OK) Error_Handler(); // Make sure it is re-initialized
		}
    }
    osDelay(100);
  }
  /* USER CODE END adcFunction */
}

/* USER CODE BEGIN Header_lcd_function */
/**
* @brief Function implementing the lcd_task thread.
* @param argument: Not used
* @retval None
*/
/* USER CODE END Header_lcd_function */
void lcd_function(void *argument)
{
  /* USER CODE BEGIN lcd_function */
  /* Infinite loop */
  for(;;)
  {	char msg8[100];
	sprintf(msg8,"LCD Function  ###### LCD #####\n");
	HAL_UART_Transmit(&huart8, (uint8_t *)msg8, strlen(msg8), 1000);
    osDelay(400);
  }
  /* USER CODE END lcd_function */
}

/**
  * @brief  Period elapsed callback in non blocking mode
  * @note   This function is called  when TIM6 interrupt took place, inside
  * HAL_TIM_IRQHandler(). It makes a direct call to HAL_IncTick() to increment
  * a global variable "uwTick" used as application time base.
  * @param  htim : TIM handle
  * @retval None
  */
void HAL_TIM_PeriodElapsedCallback(TIM_HandleTypeDef *htim)
{
  if (htim->Instance == TIM6) {
    HAL_IncTick();
  }
}

/**
  * @brief  This function is executed in case of error occurrence.
  * @retval None
  */
void Error_Handler(void)
{
  /* USER CODE BEGIN Error_Handler_Debug */
  /* User can add his own implementation to report the HAL error return state */
  __disable_irq();
  while (1)
  {
  }
  /* USER CODE END Error_Handler_Debug */
}

#ifdef  USE_FULL_ASSERT
/**
  * @brief  Reports the name of the source file and the source line number
  *         where the assert_param error has occurred.
  * @param  file: pointer to the source file name
  * @param  line: assert_param error line source number
  * @retval None
  */
void assert_failed(uint8_t *file, uint32_t line)
{
  /* USER CODE BEGIN 6 */
  /* User can add his own implementation to report the file name and line number,
     ex: printf("Wrong parameters value: file %s on line %d\r\n", file, line) */
  /* USER CODE END 6 */
}
#endif /* USE_FULL_ASSERT */

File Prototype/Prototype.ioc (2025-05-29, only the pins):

Mcu.UserName=STM32F469IITx
PA0/WKUP.Signal=SYS_WKUP
PA1.Signal=LTDC_R2
PA12.Signal=LTDC_R5
PA13.Signal=SYS_JTMS-SWDIO
PA14.Signal=SYS_JTCK-SWCLK
PA15.Signal=SYS_JTDI
PA2.Signal=LTDC_R1
PA3.Signal=LTDC_B5
PA5.Signal=LTDC_R4
PA6.Signal=LTDC_G2
PA7.Signal=QUADSPI_CLK
PA8.Signal=LTDC_R6
PA9.Signal=GPXTI9
PB0.Signal=LTDC_R3
PB1.Signal=ADCx_IN9
PB10.Signal=QUADSPI_BK1_NCS
PB11.Signal=LTDC_G5
PB12.Signal=GPIO_Output
PB13.Signal=SPI2_SCK
PB14.Signal=SPI2_MISO
PB15.GPIO_Label=LCD_T_CS
PB15.Signal=GPIO_Output
PB3.Signal=SYS_JTDO-SWO
PB4.Signal=SYS_JTRST
PB8.Signal=LTDC_B6
PB9.Signal=LTDC_B7
PC0.Signal=GPIO_Output
PC1.Signal=GPIO_Output
PC10.Signal=UART4_TX
PC11.Signal=UART4_RX
PC12.Signal=UART5_TX
PC2.Signal=ADCx_IN12
PC3.Signal=SPI2_MOSI
PC4.GPIO_Label=FLASH_RESET
PC4.Signal=GPIO_Output
PC7.Signal=GPIO_Input
PC8.GPIO_Label=ESP_RTS
PC8.Signal=GPIO_Output
PD0.Signal=FMC_D2_DA2
PD1.Signal=FMC_D3_DA3
PD10.Signal=FMC_D15_DA15
PD11.Signal=GPIO_Output
PD12.GPIO_Label=FMC_LDQM
PD12.Signal=GPIO_Output
PD13.GPIO_Label=FMC_UDQM
PD13.Signal=GPIO_Output
PD14.Signal=FMC_D0_DA0
PD15.Signal=FMC_D1_DA1
PD2.Signal=UART5_RX
PD3.Signal=LTDC_G7
PD4.GPIO_Label=ESP_RST
PD4.Signal=GPIO_Output
PD5.GPIO_Label=ESP_EN
PD5.Signal=GPIO_Output
PD6.Signal=LTDC_B2
PD8.Signal=FMC_D13_DA13
PD9.Signal=FMC_D14_DA14
PE0.Signal=UART8_RX
PE1.Signal=UART8_TX
PE10.Signal=FMC_D7_DA7
PE11.Signal=FMC_D8_DA8
PE12.Signal=FMC_D9_DA9
PE13.Signal=FMC_D10_DA10
PE14.Signal=FMC_D11_DA11
PE15.Signal=FMC_D12_DA12
PE2.Signal=QUADSPI_BK1_IO2
PE4.Signal=LTDC_B0
PE5.Signal=LTDC_G0
PE6.Signal=LTDC_G1
PE7.Signal=FMC_D4_DA4
PE8.Signal=FMC_D5_DA5
PE9.Signal=FMC_D6_DA6
PF0.Signal=FMC_A0
PF1.Signal=FMC_A1
PF10.Signal=LTDC_DE
PF11.Signal=FMC_SDNRAS
PF12.Signal=FMC_A6
PF13.Signal=FMC_A7
PF14.Signal=FMC_A8
PF15.Signal=FMC_A9
PF2.Signal=FMC_A2
PF3.Signal=FMC_A3
PF4.Signal=FMC_A4
PF5.Signal=FMC_A5
PF6.Signal=QUADSPI_BK1_IO3
PF7.Signal=GPIO_Input
PF8.Signal=QUADSPI_BK1_IO0
PF9.Signal=QUADSPI_BK1_IO1
PG0.Signal=FMC_A10
PG1.Signal=FMC_A11
PG10.Signal=LTDC_G3
PG11.Signal=LTDC_B3
PG12.Signal=LTDC_B1
PG15.Signal=FMC_SDNCAS
PG2.Signal=FMC_A12
PG4.Signal=FMC_A14_BA0
PG5.Signal=FMC_A15_BA1
PG6.Signal=LTDC_R7
PG7.Signal=LTDC_CLK
PG8.Signal=FMC_SDCLK
PH2.Signal=LTDC_R0
PH4.Signal=LTDC_G4
PH5.Signal=FMC_SDNWE
PH6.Signal=FMC_SDNE1
PH7.Signal=FMC_SDCKE1
PI10.Signal=LTDC_HSYNC
PI11.Signal=LTDC_G6
PI4.Signal=LTDC_B4
PI6.Signal=GPIO_Input
PI7.Signal=GPIO_Output
PI9.Signal=LTDC_VSYNC

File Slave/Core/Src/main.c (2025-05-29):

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
/* Includes ------------------------------------------------------------------*/
#include "main.h"

/* USER CODE BEGIN Includes */
#include "types.h"
#include "screen.h"
#include "valves.h"
#include "pumps.h"
#include "temperature_control.h"
#include "timer_us.h"
#include "DS18B20.h"
#include "GUI.h"
#include "test.h"
#include "lcd.h"
#include "FONT.h"
#include "temperature_control.h"
#include "stm32f4xx_hal_flash.h"
/* USER CODE END Includes */

SPI_HandleTypeDef hspi2;
SPI_HandleTypeDef hspi4;

TIM_HandleTypeDef htim2;
TIM_HandleTypeDef htim3;
TIM_HandleTypeDef htim10;
TIM_HandleTypeDef htim11;

UART_HandleTypeDef huart1;
UART_HandleTypeDef huart2;

/* USER CODE BEGIN PV */
uint8_t buffer[1];
uint8_t flag;
uint8_t act;
uint8_t command;
uint8_t page;
uint8_t temp_step;
float calc;
float hot_temp;
float terminal_temp;

uint32_t address = 0x08060000;
uint32_t *p = (uint32_t *)0x08060000;

DS18B20 ds18b20_terminal = {
	.SERIAL_NUMBER = {0x28, 0x50, 0x3A, 0x85, 0x00, 0x00, 0x00, 0x51},
	.temperature = 0,
	.delta = 0,
	.pos = 7
};
DS18B20 ds18b20_hot = {
	.SERIAL_NUMBER = {0x28, 0x7F, 0xF8, 0x87, 0x00, 0x00, 0x00, 0x65},
	.temperature = 0,
	.delta = 0,
	.pos = 6
};

Water water;
Valve valve;
ERR err;
ERR_STRING err_string;

Valve valve ={
		.current_steps = 0,
		.degPerStep = 1.8,
		.steps = 0,
		.save_step = 0,
		.aprox = 0
};

Pressed pressed ={
		.Y_ = 0x00, // 0b0000 0 <1,4,7, CLR> <2, 5, 8, 0> <3, 6, 9, SET>
		.X_ = 0x00	// 0b<1, 2, 3> <4, 5, 6> <7, 8, 9> <CLR, 0, SET> 0000
};

Button button ={
		.c = {0},
		.value = -1,
		.data = 0,
		.valid = false,
		.n = 0,
		.rst = false,
		.set = false,
		.temp_set = 0
};

Page PAGE = {
	.button = &button,
	.flash_position = FLASH_ADDRESS,
	.hot_temp = &ds18b20_hot,
	.terminal_temp = &ds18b20_terminal,
	.valve = &valve
};

CMD cmd = {
	.args[0] = {0},
	.args[1] = {0},
	.args[2] = {0},
	.args[3] = {0},
	.cmd_all = {0},
	.command = {0},
	.origin = {0},
	.protocol = {0},
	.status_busy = false
};

uint8_t rxBuffer[2] = {0};
/* USER CODE END PV */

void SystemClock_Config(void);
static void MX_GPIO_Init(void);
static void MX_USART1_UART_Init(void);
static void MX_USART2_UART_Init(void);
static void MX_TIM3_Init(void);
static void MX_TIM10_Init(void);
static void MX_SPI2_Init(void);
static void MX_TIM11_Init(void);
static void MX_TIM2_Init(void);
static void MX_SPI4_Init(void);
/* USER CODE BEGIN PFP */
void HAL_NVIC_EnableIRQ(IRQn_Type IRQn);
void getFloatString(char *buffer, float number);

 float temp_set_f;
 char temp_set_c[1];
 char temp_set_c_number[30];


/* USER CODE END PFP */

/**
  * @brief  The application entry point.
  * @retval int
  */
int main(void)
{

  /* MCU Configuration--------------------------------------------------------*/

  /* Reset of all peripherals, Initializes the Flash interface and the Systick. */
  HAL_Init();

  /* Configure the system clock */
  SystemClock_Config();

  /* Initialize all configured peripherals */
  MX_GPIO_Init();
  MX_USART1_UART_Init();
  MX_USART2_UART_Init();
  MX_TIM3_Init();
  MX_TIM10_Init();
  MX_SPI2_Init();
  MX_TIM11_Init();
  MX_TIM2_Init();
  MX_SPI4_Init();
  /* USER CODE BEGIN 2 */
  TIMER_US_INIT();
  LCD_Init();
  LCD_DrawPage1();
  VALVE_MODE_FULL_CW();
  HAL_UART_Receive_IT(&huart1, rxBuffer, 1);

  GPIOA->BSRR = (1U << (16));
  HAL_Delay(1000);
  GPIOA->BSRR = (1U << (0));
  GPIOB->BSRR = (1U << 8); // Enable ESP
  T_CS_SET;
  flag = 0x00;
  page = 0x01;
  command = 0x0;
  act = 0x00;

  uint32_t *p = (uint32_t *)FLASH_ADDRESS;
  int h = *p;
  LCD_UpdateFlash(h);
  HAL_Delay(1000);

  ds18b20_terminal.temperature = ds18b20_get_temperature(&ds18b20_terminal, false, &huart2);
  ds18b20_hot.temperature = ds18b20_get_temperature(&ds18b20_hot, false, &huart2);

  LCD_UpdateTemperature(&ds18b20_terminal, ds18b20_terminal.temperature);
  LCD_UpdateTemperature(&ds18b20_hot, ds18b20_hot.temperature);

  // Handle initial positioning -> Return valve to its 0 positioning
  // Raise STALL flag if Hot temperature is lower then minimum
  //VALVE_CONTROL_HANDLE_INIT(&valve);
  h = *p;
  //char msg[20] = "HELLO YOU BUSY";
  LCD_UpdateFlash(h);
  HAL_Delay(1000);
  /* USER CODE END 2 */

  /* Infinite loop */
  /* USER CODE BEGIN WHILE */
  char terminalBuffer[100]; char hotBuffer[100];
  char updateMsg[200];

	while(1){
    /* USER CODE END WHILE */
		//LCD_typeDebug("looping");
    /* USER CODE BEGIN 3 */
		// Handle command flags
		COMMAND_HANDLE(&htim10, &htim2, &command);
		// Handle touch screen interrupt
		if((flag & SCAN_PAD) != 0){
			SCAN_HANDLE(&ds18b20_hot, &valve, &hspi4, &huart2, &button, &pressed, &act, &flag, &PAGE);
			flag &= (~SCAN_PAD);}

		// Update temperatures, storing them in the Struct.
		if((act & TEMP_UPDATE_) == TEMP_UPDATE_){
			LCD_typeDebug("reading temperature");
			terminal_temp = ds18b20_get_temperature(&ds18b20_terminal, false, &huart2);
			hot_temp = ds18b20_get_temperature(&ds18b20_hot, false, &huart2);

			ds18b20_terminal.delta = terminal_temp - ds18b20_terminal.temperature;
			ds18b20_hot.delta = hot_temp - ds18b20_hot.temperature;

			ds18b20_terminal.temperature = terminal_temp;
			ds18b20_hot.temperature = hot_temp;
			act = act & (~TEMP_UPDATE_);
		    // Update the User's screen controller
			getFloatString(terminalBuffer, terminal_temp);
			getFloatString(hotBuffer, hot_temp);
			sprintf(updateMsg, "UPDATE %d %s %s %d", button.data, terminalBuffer, hotBuffer, valve.current_steps);
		    HAL_UART_Transmit(&huart1, (uint8_t *)updateMsg,strlen(updateMsg), 100);}


		if(((act & TEMP_GET_VALV_APROX) == TEMP_GET_VALV_APROX)){
			VALVE_CONTROL_APROX(&valve); // Open Valve to approximate position
			act &= (~TEMP_GET_VALV_APROX);
			command |= RUN;} // Clear bit flag

		if(((command & RUN) == RUN) && (command & RUN_) == RUN_){
			VALVE_CONTROL_RUN(&valve, &ds18b20_terminal, &button);
			command = command & (~RUN_);}

		switch (page){
			case 0x01: // Home Page
				LCD_HANDLE_PAGE_1(&PAGE, &act, &command);
				break;
			case 0x02: // Readings Page
				break;
		}

		HAL_Delay(10);
	}
  /* USER CODE END 3 */
}

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
/* USER CODE BEGIN 4 */

void getFloatString(char *buffer, float number){
	int intNumber = (int)floor(number);
	int floatNumber = (int)((number - (float)intNumber)*10000);
	sprintf(buffer, "%d,%d", intNumber, floatNumber);
}

void ERR_INIT(ERR_STRING *err_String){
}
/* USER CODE END 4 */
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


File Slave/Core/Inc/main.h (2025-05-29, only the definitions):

#define LCD_CS_Pin GPIO_PIN_0
#define LCD_CS_GPIO_Port GPIOH
#define Valve_M1_Pin GPIO_PIN_0
#define Valve_M1_GPIO_Port GPIOC
#define Valve_M2_Pin GPIO_PIN_1
#define Valve_M2_GPIO_Port GPIOC
#define Valve_M3_Pin GPIO_PIN_2
#define Valve_M3_GPIO_Port GPIOC
#define Valve_EN_Pin GPIO_PIN_3
#define Valve_EN_GPIO_Port GPIOC
#define ESP_RST_Pin GPIO_PIN_0
#define ESP_RST_GPIO_Port GPIOA
#define ESP_RTS_Pin GPIO_PIN_4
#define ESP_RTS_GPIO_Port GPIOA
#define ESP_CTS_Pin GPIO_PIN_5
#define ESP_CTS_GPIO_Port GPIOA
#define ESP_IO4_Pin GPIO_PIN_6
#define ESP_IO4_GPIO_Port GPIOA
#define ESP_IO5_Pin GPIO_PIN_7
#define ESP_IO5_GPIO_Port GPIOA
#define Valve_RST_Pin GPIO_PIN_4
#define Valve_RST_GPIO_Port GPIOC
#define Valve_CLK_Pin GPIO_PIN_5
#define Valve_CLK_GPIO_Port GPIOC
#define LCD_RST_Pin GPIO_PIN_1
#define LCD_RST_GPIO_Port GPIOB
#define LCD_DC_Pin GPIO_PIN_2
#define LCD_DC_GPIO_Port GPIOB
#define T_CS_Pin GPIO_PIN_12
#define T_CS_GPIO_Port GPIOB
#define Valve_CCW_Pin GPIO_PIN_6
#define Valve_CCW_GPIO_Port GPIOC
#define Valve_LATCH_Pin GPIO_PIN_7
#define Valve_LATCH_GPIO_Port GPIOC
#define Valve_TQ_Pin GPIO_PIN_8
#define Valve_TQ_GPIO_Port GPIOC
#define LCD_T_DIN_Pin GPIO_PIN_15
#define LCD_T_DIN_GPIO_Port GPIOA
#define Valve_ALERT_Pin GPIO_PIN_10
#define Valve_ALERT_GPIO_Port GPIOC
#define OneWire_Pin GPIO_PIN_5
#define OneWire_GPIO_Port GPIOB
#define ESP_EN_Pin GPIO_PIN_8
#define ESP_EN_GPIO_Port GPIOB
#define LCD_CSB9_Pin GPIO_PIN_9
#define LCD_CSB9_GPIO_Port GPIOB
#define ERROR_COLD_WATER "Cold Water out of acceptable temperature inlet."
#define ERROR_HOT_WATER "Hot Water out of acceptable temperature inlet."
#define ERROR_TEMPERATURE_SET "Not a valid input temperature."

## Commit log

2025-06-02 Create kicadfiles
2025-06-02 Create motorFiles

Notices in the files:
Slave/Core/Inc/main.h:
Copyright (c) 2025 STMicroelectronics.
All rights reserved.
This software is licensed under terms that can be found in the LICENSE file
